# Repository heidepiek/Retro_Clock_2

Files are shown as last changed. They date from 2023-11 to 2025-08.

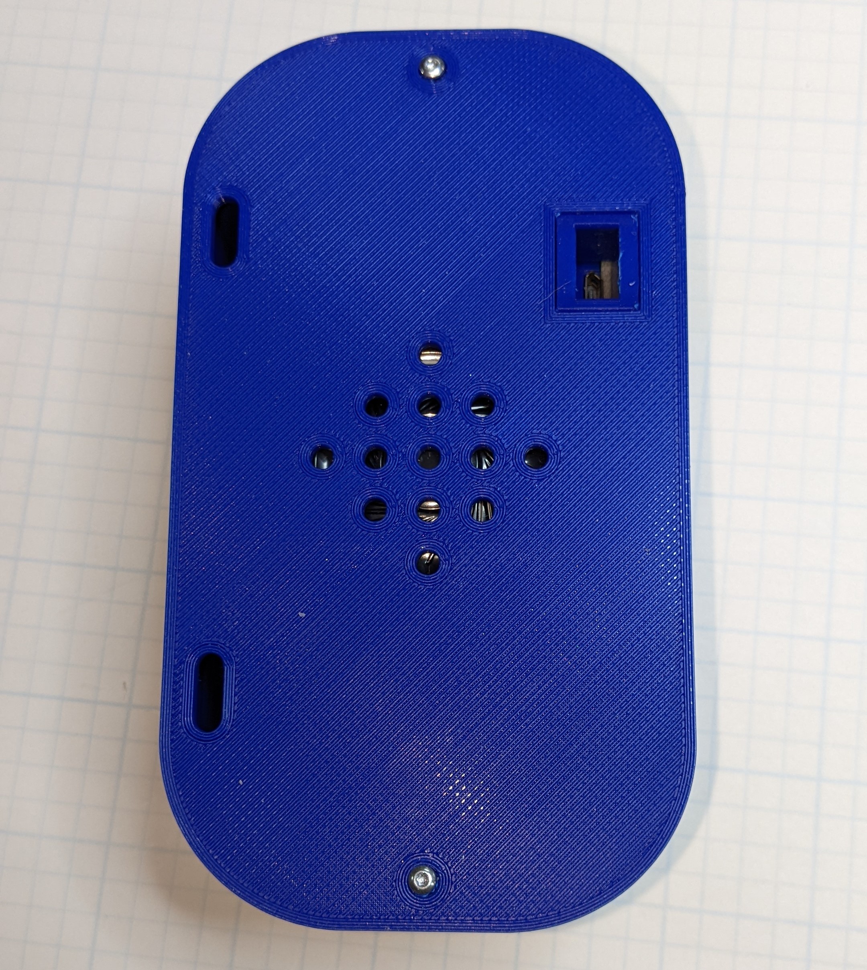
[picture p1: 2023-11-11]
Images/Rear_Cover_screws_Installed.jpg

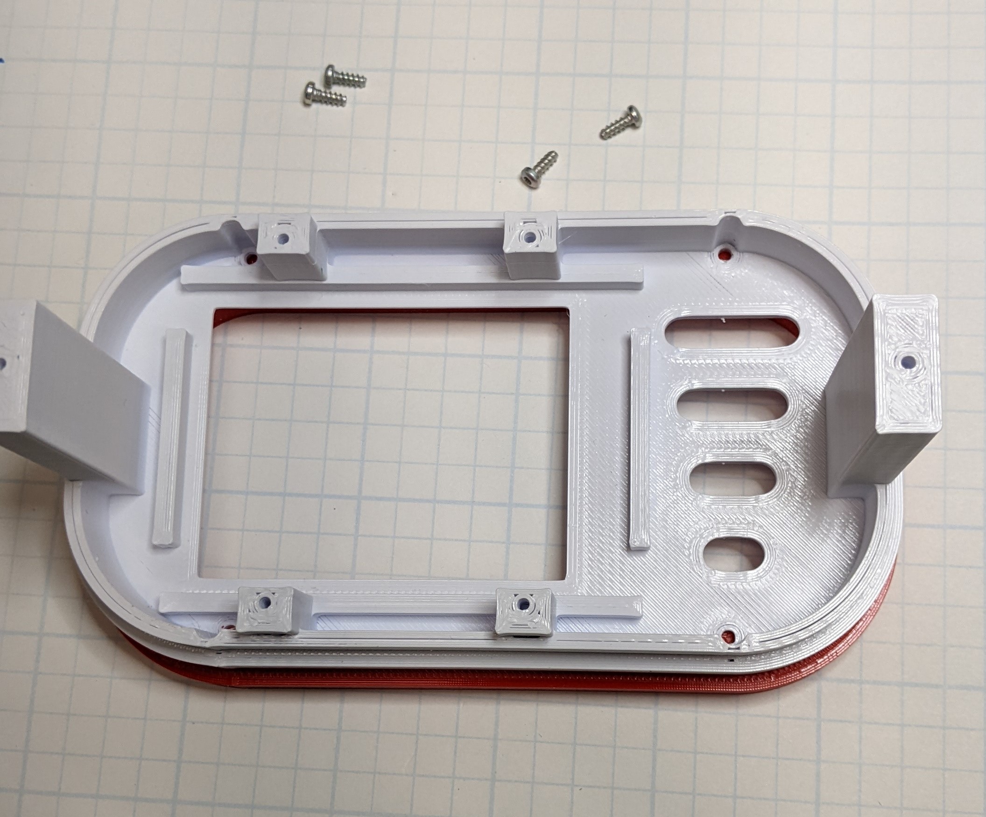
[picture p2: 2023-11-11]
Images/Bezel&TrimParts.jpg

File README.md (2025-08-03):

Pacman Clock

# Retro Clock 2

This is a personal customized version of the original ESP32 Pacman Clock project.  
I've added some visual and functional enhancements to suit my own preferences.

### My additions:
- Blinking dots between hours and minutes
- Rectangle around the time
- Date and day display
- Text below the time: “ESP32 Pacman Clock”
- Pacman and ghost icons

The rest of this README reflects the original project, which deserves full credit for the excellent foundation.

# Retro_Clock_2
 Improved version of Retro_Clock
 1. Redesigned all of clock case parts with freeCAD. results in cleaner parts.
 2. All STL files are from freeCAD redesign.
 3. Minor firmware changes. Added menu items.
 4. PCB redesign to use better audio amplifier.
 
# Retro_Clock
This is a highly modified version of TechKiwiGadgets clock found on 

1. Instructables     https://www.instructables.com/ESP32-Pacman-Clock/
2. Makerbot Thingiverse (ESP32 Pacman Clock)    https://www.thingiverse.com/thing:5136672

Modifications:
1. Changed TFT display to an SPI version which has a much improved Touch interface.
2. Added SPIFFS to support files for data and images. This freed up memory and added flexability.
3. Added support for optional RTC (real time clock IC). Improves time keeping accuracy.
4. Added support for LDR (light dependent resistor) so that display is dimmed at night.
5. Added audio amplifier (LM386) and volume control via touch screen.
6. Redesigned user interface (Touch menu) to support added features.
7. Made many changes to firmware to improve speed and readability. 
8. Designed PCB to support above mentioned changes.
9. Redesigned 3D printed parts to support hardware changes.

TFT_eSPI library:
1. The TFT_eSPI library requires it be changed to support each particular build (unusal but that's way way it works).
2. The file User_Setup_Select.h specifies which setup file in the User_Setups directory is to be used.
3. Added to the User_Setups directory is the file Setup_Pacman_Clock.h which contains the specifies the configuration and features (Touch) used by this project.
4. Move the file "Setup_Pacman_Clock.h" into directory   ...Arduino/libraries/TFT_eSPI/User_Setups
5. Move the file "User_Setup_Select.h" into the directory    ...Arduino/libraries/TFT_eSPI   (replaces the existing User_Setup_Select.h file). 

Tools:
1. Arduino IDE 1.8.19, Board: DOIT ESP32 DEVKIT V1
2. Initialize SPIFFS using Arduino IDE  "Tools/ESP32 Sketch Data Upload" (which will initializee SPIFFS and upload all the files from the Data directory).
3. Creality Slicer, PLA, 0.2mm, no supports.

Additional Notes:
1. 	Arduino Sketch (IDE) Version 1.8.19
2.	Board Manager -> esp32 by Espressif Systems Version 1.0.6
3.	Libraries used:

		TFT_eSPI at version 2.5.0
		RTClib at version 2.1.1
		Wire at version 1.0.1
		SPIFFS at version 1.0
		FS at version 1.0
		XT_DAC_Audio
		Time at version 1.6.1
		Adafruit_BusIO at version 1.14.1
4.	TFT_eSPI setup file contains (see TFT_eSPI folder in Arduino/libraries):

		#define USER_SETUP_ID 900
		#define ILI9341_DRIVER
		#define TFT_MISO	19
		#define TFT_MOSI	23
		#define TFT_SCLK	18
		#define TFT_CS		15
		#define TFT_DC		4
		#define TFT_RST		2

		#define TOUCH_CS	5		// Required to enable Touch, getTouch()

		#define LOAD_GLCD
		#define LOAD_FONT2
		#define LOAD_FONT4
		#define LOAD FONT6
		#define LOAD_FONT7
		#define LOAD_FONT8
		#define LOAD_GFXFF
		#define SMOOTH_FONT

		#define SPI_FREQUENCY 27000000					// 27 MHz
		#define SPI_READ_FREQUENCY 20000000				// 20 MHz
		#define SPI_TOUCH_FREQUENCY 2500000				// 2.5 MHz

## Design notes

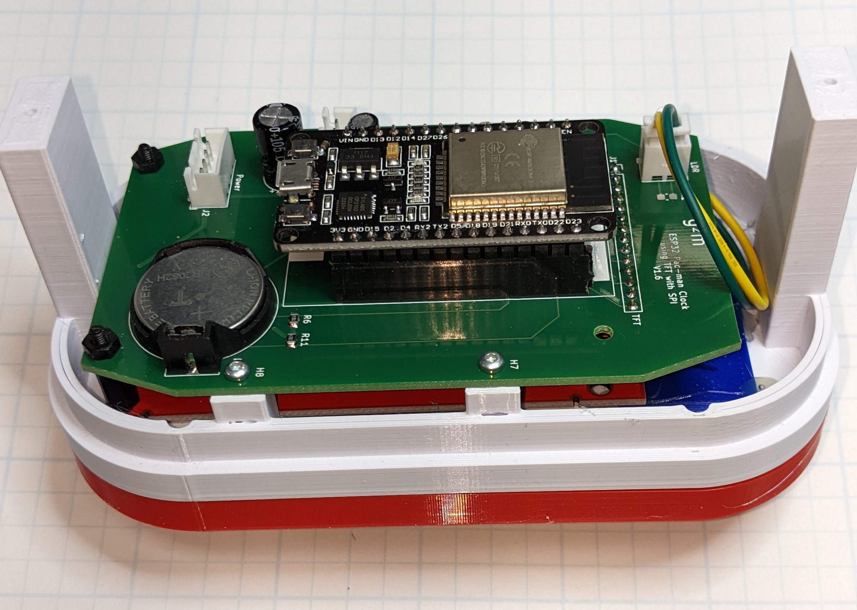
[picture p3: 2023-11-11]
Images/Bezel_with_PCB.jpg

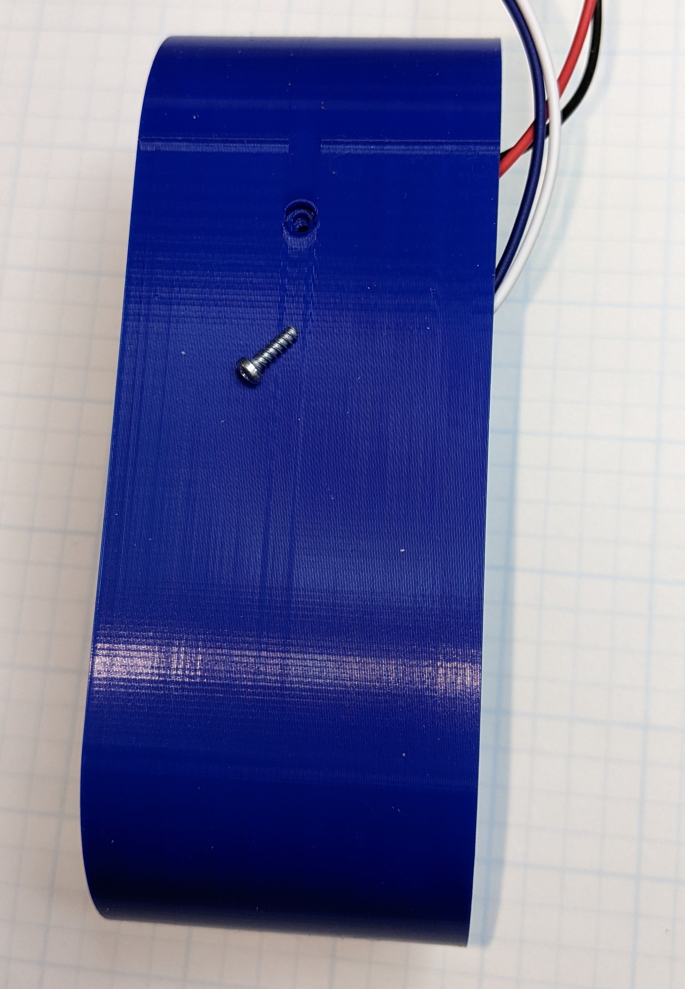
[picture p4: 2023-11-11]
Images/USB_Securing_Screw.jpg

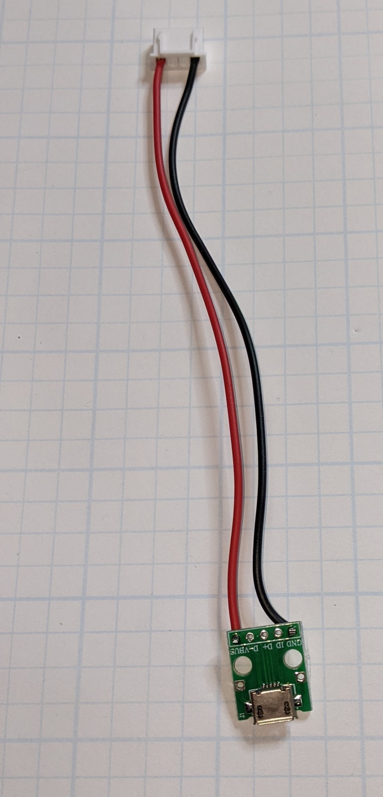
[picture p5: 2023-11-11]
Images/USB.jpg

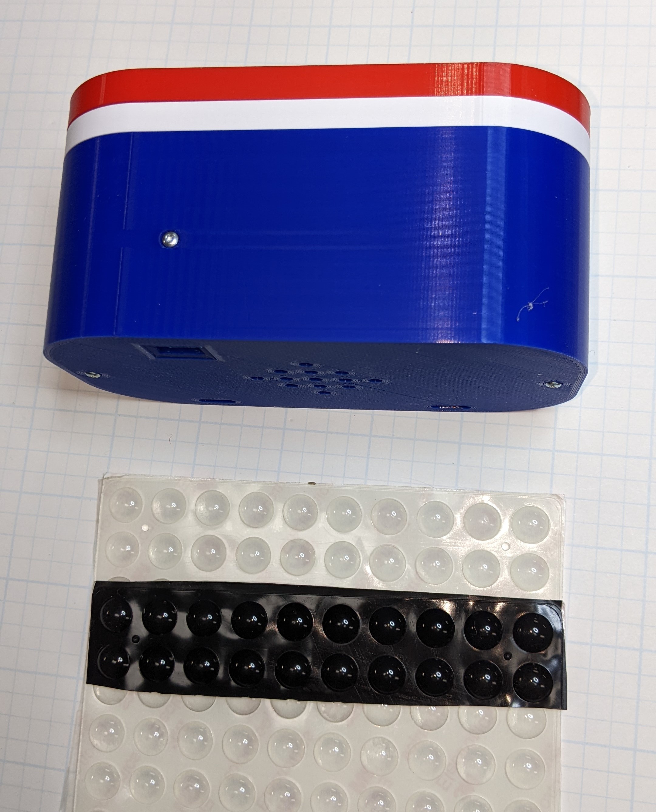
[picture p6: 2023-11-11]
Images/Clock_Case_&_Rubber_Feet.jpg

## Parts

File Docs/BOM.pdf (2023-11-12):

Component Count: | 33
Ref | Value | Footprint | Amazon (search) | Notes
BT1 | Holder | KiCab_g2m_Lib:2032BatteryHolderHoriz | | See note on U3,. Used battery holder from
| | | | DS3231 board.
C1 | 390nF | Capacitor_SMD:C_0805_2012Metric_Pad | 0805 SMD Capacitor Assorted Kit 1pF-1uF Chip
| | | Ceramic Capacitor
C2 | 1uF | Capacitor_SMD:C_1206_3216Metric_Pad | 1206 SMD Capacitor Assorted Kit 10P-22UF Chip
| | | Ceramic Capacitor
C3 | 470uF | Capacitor_THT:CP_Radial_D8.0mm_P3.50mm | lectrolytic Capacitor 470uF 16V with Aluminum Radial
| | | Leads 470UF-16V-8X12
C4 | 1uF | Capacitor_SMD:C_1206_3216Metric_Pad | 1206 SMD Capacitor Assorted Kit 10P-22UF Chip
| | | Ceramic Capacitor
C5 | 10uF | Capacitor_THT:CP_Radial_D4.0mm_P1.50mm | Electrolytic Capacitor 10uF 25V with Aluminum Radial
| | | Leads 10UF-25V-4X7
C6 | 1uF | Capacitor_SMD:C_0805_2012Metric_Pad | 0805 SMD Capacitor Assorted Kit 1pF-1uF Chip
| | | Ceramic Capacitor
C8 | 100nF | Capacitor_SMD:C_0805_2012Metric_Pad | 0805 SMD Capacitor Assorted Kit 1pF-1uF Chip
| | | Ceramic Capacitor
D1 | 1N4148W | Diode_SMD:D_SOD-123 | | See U3. Used diode from DS3231 board.
H1 | MountingHole | MountingHole:MountingHole_2.7mm_M2.5_DIN965
H2 | MountingHole | MountingHole:MountingHole_2.7mm_M2.5_DIN965
H3 | MountingHole | MountingHole:MountingHole_2.7mm_M2.5_DIN965
H4 | MountingHole | MountingHole:MountingHole_2.7mm_M2.5_DIN965
H5 | MountingHole | MountingHole:MountingHole_2.7mm_M2.5_DIN965
H6 | MountingHole | MountingHole:MountingHole_2.7mm_M2.5_DIN965
H7 | MountingHole | MountingHole:MountingHole_2.7mm_M2.5_DIN965
H8 | MountingHole | MountingHole:MountingHole_2.7mm_M2.5_DIN965
J1 | TFT Connector | Connector_PinSocket_2.54mm:PinSocket_1x14_P2.54mm_Vertical | 40 Pin 2.54mm Single Row Straight Female PCB
| | | Header Connector Strip | Cut strip to required length - 14 pins.
J2 | Power | Connector_JST:JST_XH_B4B-XH-A_1x04_P2.50mm_Vertical | JST-XH 2.54mm Connector Kit, 2.54mm Male and
| | | Female 2/3/4/5/6 Pin Header Housing Connector
J3 | Speaker | Connector_JST:JST_XH_B2B-XH-A_1x02_P2.50mm_Vertical | JST-XH 2.54mm Connector Kit, 2.54mm Male and
| | | Female 2/3/4/5/6 Pin Header Housing Connector
J4 | LDR | Connector_JST:JST_XH_B2B-XH-A_1x02_P2.50mm_Vertical | JST-XH 2.54mm Connector Kit, 2.54mm Male and
| | | Female 2/3/4/5/6 Pin Header Housing Connector
R1 | 20k | Resistor_SMD:R_0805_2012Metric_Pad | 0805 SMD Resistor Kit 0-10M Ω ohm
R2 | 200 | Resistor_SMD:R_0805_2012Metric_Pad | 0805 SMD Resistor Kit 0-10M Ω ohm | Only installed if LDR option is not used.
R6 | 4.7k | Resistor_SMD:R_0805_2012Metric_Pad | 0805 SMD Resistor Kit 0-10M Ω ohm
R7 | 10k | Resistor_SMD:R_0805_2012Metric_Pad | 0805 SMD Resistor Kit 0-10M Ω ohm
R8 | 20k | Resistor_SMD:R_0805_2012Metric_Pad | 0805 SMD Resistor Kit 0-10M Ω ohm
R10 | 20k | Resistor_SMD:R_0805_2012Metric_Pad | 0805 SMD Resistor Kit 0-10M Ω ohm
R11 | 4.7k | Resistor_SMD:R_0805_2012Metric_Pad | 0805 SMD Resistor Kit 0-10M Ω ohm
R12 | 200 | Resistor_SMD:R_0805_2012Metric_Pad | 0805 SMD Resistor Kit 0-10M Ω ohm
SW1 | Recal Touch | Tactile-switch:FSM2JRT_gm | 6x6x7mm 2 Pin Panel PCB Momentary Tactile Tact
| | | Push Button Switch Through Hole Installation
U1 | LM4890M_NOPB | Package_SO:SOIC-8_3.9x4.9mm_P1.27mm | | Mouser: 926-LM4890M/NOPB
U2 | ESP-WROOM-32S | If Socketed (recommended) - uses two of the following connectors
| | Connector_PinSocket_2.54mm:PinSocket_1x15_P2.54mm_Vertical | 40 Pin 2.54mm Single Row Straight Female PCB
| | | Header Connector Strip | Cut strip to required length - 15 pins.
| | | | Quantity 2.

Retro Clock 2

U3 | DS3231M | Package_SO:SOIC-16W_7.5x10.3mm_P1.27mm

DS3231 AT24C32 Clock Module Real Time Clock Module IIC RTC Module

Ordering from Amazon is much less expensive. Although you will need to remove the DS3231 and battery holder from the board.

Battery | LIR2032 | Rechargeable 2032 Battery, 3.7V

LIR2032 Rechargeable Batteries 3.7V with High Capacity 70mA
TFT | 2.8 inch TFT with Touch, SPI interface. | ILI9341 2.8" SPI TFT LCD Display Touch Panel 240X320
ESP32S | ESP32S | ESP32S Module - 30 pins (2 rows of 15 pins)

ESP-WROOM-32 ESP32 ESP-32S Development Board 2.4GHz Dual-Mode WiFi + Bluetooth Dual Cores Microcontroller Processor Integrated with Antenna RF AMP Filter AP STA Compatible

Screws - 6mm
Qty 9

Torx Plus Rounded Head Thread-Forming Screws for Plastic, Zinc-Plated Steel, M2.26 Size, 6 mm Long

McMaster-Carr mcmaster.com

### 4 to mount Bezel Trim to Bezel 4 to mount PCB to Bezel 1 to mount USB Bracket to Rear Case

Screws - 8mm
Qty 2

Torx Plus Rounded Head Thread-Forming Screws for Plastic, Zinc-Plated Steel, M2.26 Size, 8 mm Long

McMaster-Carr mcmaster.com | 2 to mount Rear Case to Bezel
Screws - 10mm
Qty 2

Torx Plus Rounded Head Thread-Forming Screws for Plastic, Zinc-Plated Steel, M2.26 Size, 10 mm Long

McMaster-Carr mcmaster.com | 2 to mount USB Lock and USB Connector board to USB bracket

Glue

Either hot-glue or super-glue Decal to Bezel. Hot glue LDR to Decal.

Hardware

Plug-in Devices

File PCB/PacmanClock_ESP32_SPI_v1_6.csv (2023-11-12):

Source: | C:\Users\gmaur\Documents\GitHub\Retro_Clock_2\PCB\PacmanClock_ESP32_SPI_v1_6.sch
Date: | 11/12/2023 1:09:07 PM
Tool: | Eeschema (5.1.10)-1
Component Count: | 33
Ref | Value | Footprint | Datasheet | Manufacturer | Vendor
BT1 | LIR2032 | KiCab_g2m_Lib:2032BatteryHolderHoriz | ~
C1 | 390nF | Capacitor_SMD:C_0805_2012Metric_Pad1.18x1.45mm_HandSolder | ~
C2 | 1uF | Capacitor_SMD:C_1206_3216Metric_Pad1.33x1.80mm_HandSolder | ~
C3 | 470uF | Capacitor_THT:CP_Radial_D8.0mm_P3.50mm | ~
C4 | 1uF | Capacitor_SMD:C_1206_3216Metric_Pad1.33x1.80mm_HandSolder | ~
C5 | 10uF | Capacitor_THT:CP_Radial_D4.0mm_P1.50mm | ~
C6 | 1uF | Capacitor_SMD:C_0805_2012Metric_Pad1.18x1.45mm_HandSolder | ~
C8 | 100nF | Capacitor_SMD:C_0805_2012Metric_Pad1.18x1.45mm_HandSolder | ~
D1 | 1N4148W | Diode_SMD:D_SOD-123 | https://www.vishay.com/docs/85748/1n4148w.pdf
H1 | MountingHole | MountingHole:MountingHole_2.7mm_M2.5_DIN965 | ~
H2 | MountingHole | MountingHole:MountingHole_2.7mm_M2.5_DIN965 | ~
H3 | MountingHole | MountingHole:MountingHole_2.7mm_M2.5_DIN965 | ~
H4 | MountingHole | MountingHole:MountingHole_2.7mm_M2.5_DIN965 | ~
H5 | MountingHole | MountingHole:MountingHole_2.7mm_M2.5_DIN965 | ~
H6 | MountingHole | MountingHole:MountingHole_2.7mm_M2.5_DIN965 | ~
H7 | MountingHole | MountingHole:MountingHole_2.7mm_M2.5_DIN965 | ~
H8 | MountingHole | MountingHole:MountingHole_2.7mm_M2.5_DIN965 | ~
J1 | TFT | Connector_PinSocket_2.54mm:PinSocket_1x14_P2.54mm_Vertical | ~
J2 | Power | Connector_JST:JST_XH_B4B-XH-A_1x04_P2.50mm_Vertical | ~
J3 | Speaker | Connector_JST:JST_XH_B2B-XH-A_1x02_P2.50mm_Vertical | ~
J4 | LDR | Connector_JST:JST_XH_B2B-XH-A_1x02_P2.50mm_Vertical | ~
R1 | 20k | Resistor_SMD:R_0805_2012Metric_Pad1.20x1.40mm_HandSolder | ~
R2 | 200 | Resistor_SMD:R_0805_2012Metric_Pad1.20x1.40mm_HandSolder | ~
R6 | 4.7k | Resistor_SMD:R_0805_2012Metric_Pad1.20x1.40mm_HandSolder | ~
R7 | 10k | Resistor_SMD:R_0805_2012Metric_Pad1.20x1.40mm_HandSolder | ~
R8 | 20k | Resistor_SMD:R_0805_2012Metric_Pad1.20x1.40mm_HandSolder | ~
R10 | 20k | Resistor_SMD:R_0805_2012Metric_Pad1.20x1.40mm_HandSolder | ~
R11 | 4.7k | Resistor_SMD:R_0805_2012Metric_Pad1.20x1.40mm_HandSolder | ~
R12 | 200 | Resistor_SMD:R_0805_2012Metric_Pad1.20x1.40mm_HandSolder | ~
SW1 | Recal Touch | Tactile-switch:FSM2JRT_gm | ~
U1 | LM4890M_NOPB | Package_SO:SOIC-8_3.9x4.9mm_P1.27mm | http://www.ti.com/lit/ds/symlink/lm4890.pdf
U2 | ESP-WROOM-32S | ESP32-Footprints:ESP-WROOM-32S
U3 | DS3231M | Package_SO:SOIC-16W_7.5x10.3mm_P1.27mm | http://datasheets.maximintegrated.com/en/ds/DS3231.pdf

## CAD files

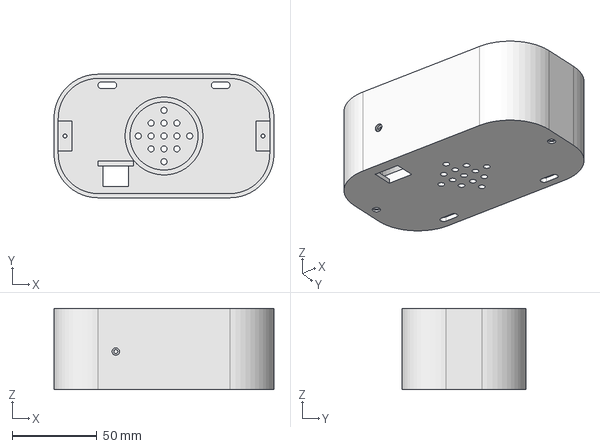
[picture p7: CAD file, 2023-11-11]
Case/freeCAD_Files/ClockAssembly.FCStd
130.0 x 73.0 x 48.0 mm

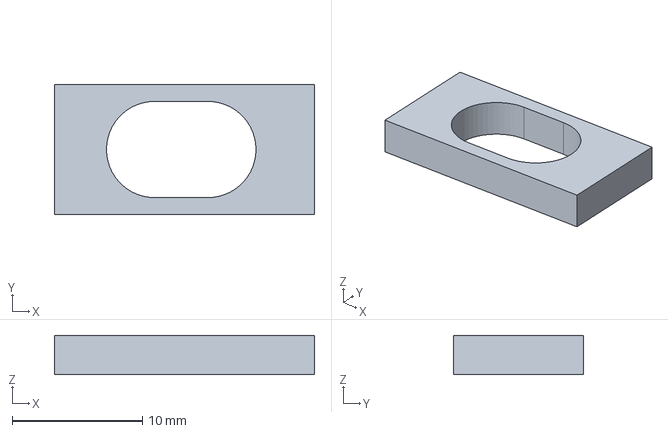
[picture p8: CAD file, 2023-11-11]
Case/freeCAD_Files/NU_USB_C_Test.FCStd
20.0 x 10.0 x 3.00 mm

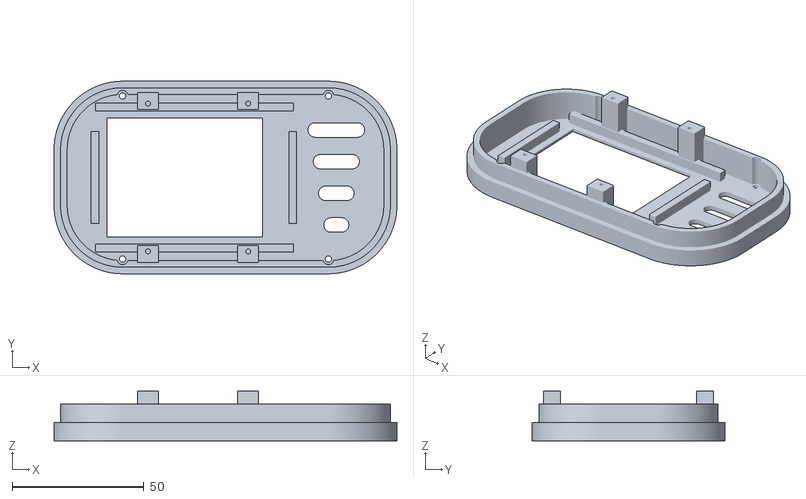
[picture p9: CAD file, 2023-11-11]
Case/STL_Files/NU_CLOCK_BEZEL-Body.stl
130.0 x 73.0 x 18.9

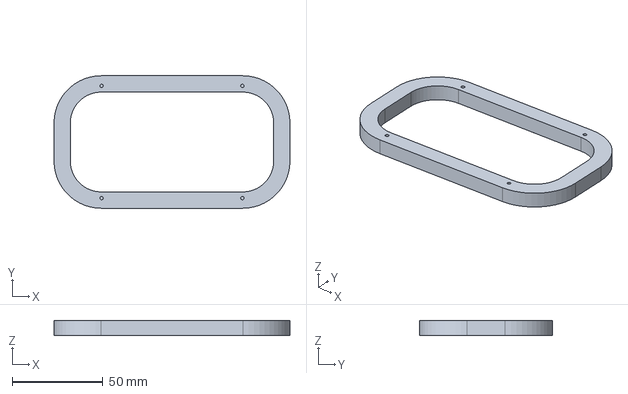
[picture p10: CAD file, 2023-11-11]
Case/freeCAD_Files/NU_BEZEL_TRIMStd.FCStd
130.0 x 73.0 x 8.00 mm

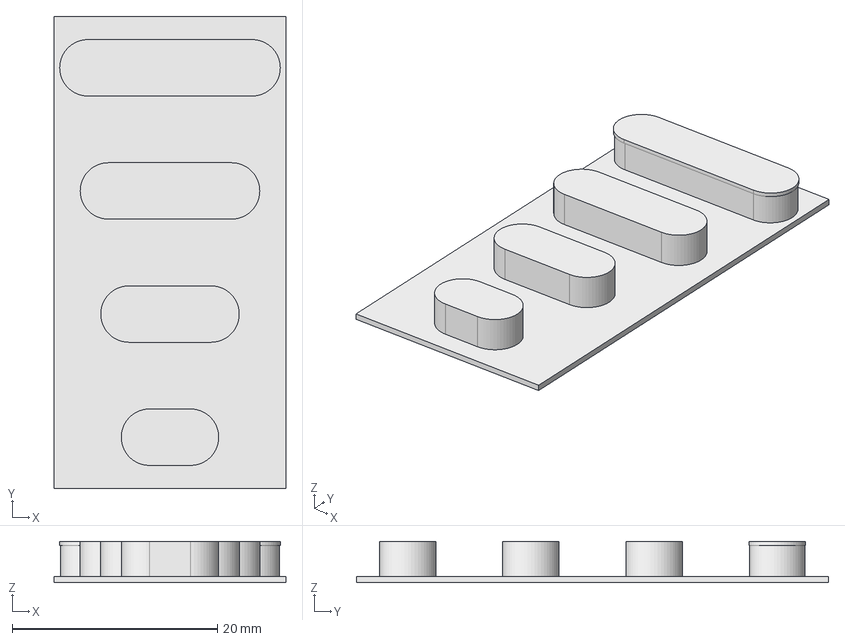
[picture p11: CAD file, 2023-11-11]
Case/freeCAD_Files/NU_DECAL.FCStd
22.6 x 46.0 x 4.00 mm

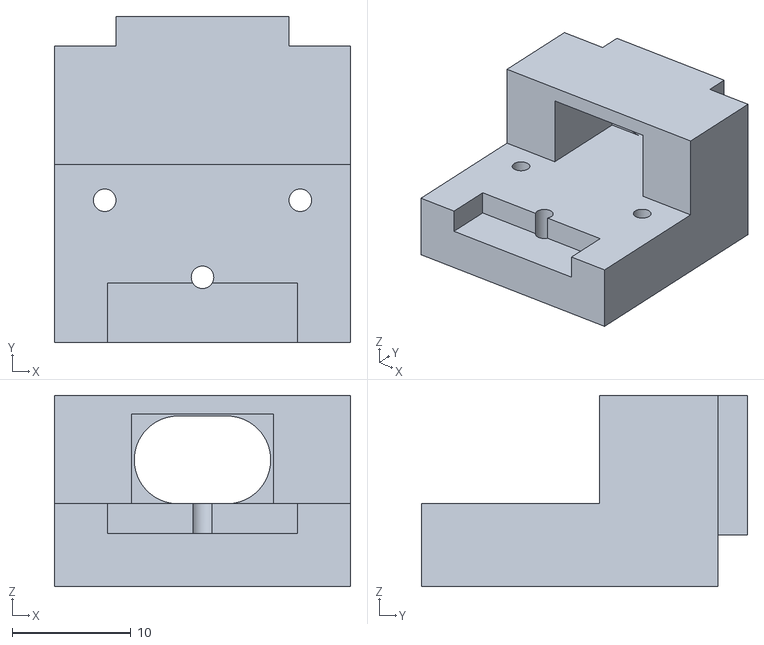
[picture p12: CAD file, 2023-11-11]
Case/STL_Files/NU_USB_C_Bracket2.stl
25.0 x 27.5 x 16.1

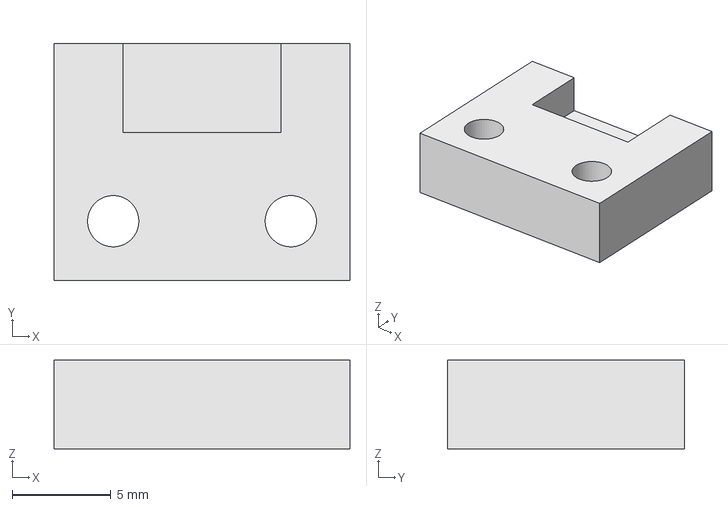
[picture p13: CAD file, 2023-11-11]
Case/freeCAD_Files/NU_USB_Micro_Lock.FCStd
15.0 x 12.0 x 4.50 mm

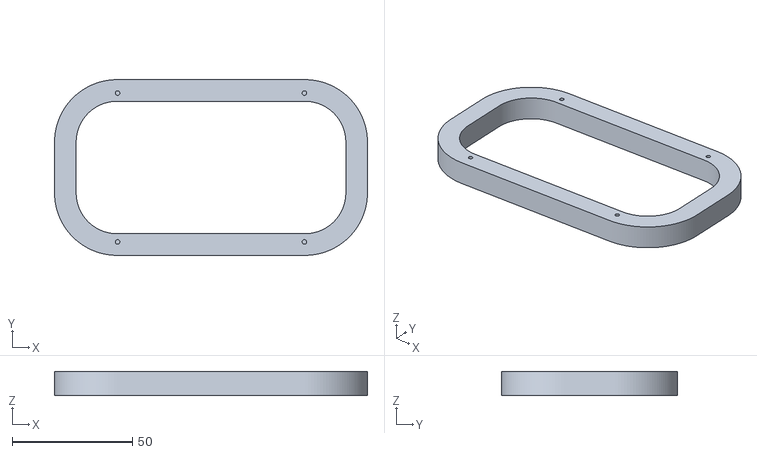
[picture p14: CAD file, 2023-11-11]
Case/STL_Files/NU_BEZEL-Part.stl
130.0 x 73.0 x 10.0

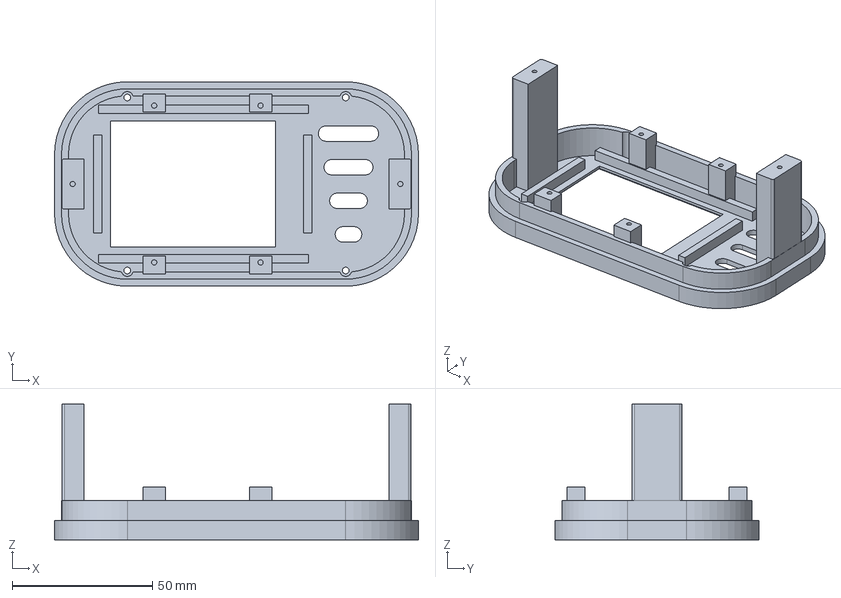
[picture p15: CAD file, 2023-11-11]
Case/freeCAD_Files/NU_CLOCK_BEZEL.FCStd
130.0 x 73.0 x 48.5 mm

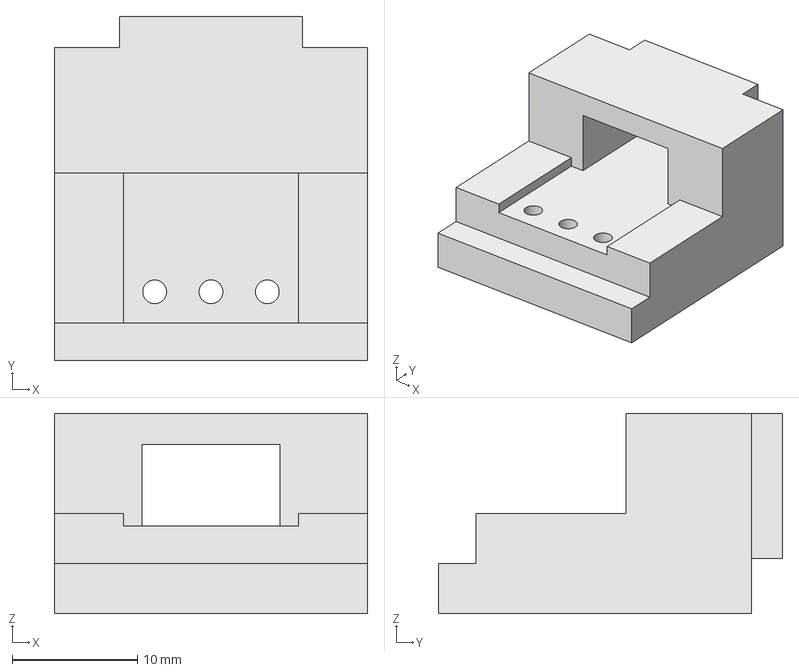
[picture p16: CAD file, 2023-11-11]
Case/freeCAD_Files/NU_USB_Micro_Bracket.FCStd
25.0 x 27.5 x 16.0 mm

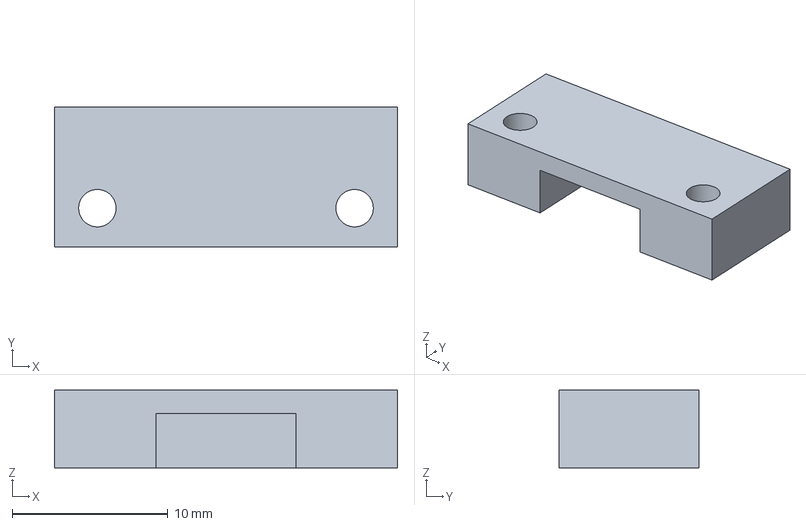
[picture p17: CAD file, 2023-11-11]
Case/freeCAD_Files/NU_USB_C_Lock.FCStd
22.0 x 9.00 x 5.00 mm

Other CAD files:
Case/freeCAD_Files/NU_CLOCK_CASE.FCStd
Case/STL_Files/NU_CLOCK_CASE-PartBody.stl
Case/STL_Files/NU_BEZEL_Trim.stl
Case/freeCAD_Files/NU_BEZEL.FCStd
Case/STL_Files/NU_BEZEL-PartBody1.stl
Case/freeCAD_Files/NU_USB_C_Bracket.FCStd
Case/freeCAD_Files/NU_DECAL2.FCStd
Case/STL_Files/NU_BEZEL.stl
Case/STL_Files/NU_CLOCK_CASE.stl
Case/STL_Files/NU_DECAL.stl
Case/STL_Files/NU_DECAL2.stl
Case/STL_Files/NU_USB_C_Bracket.stl
Case/STL_Files/NU_USB_C_Lock.stl
Case/STL_Files/NU_USB_C_Test.stl
Case/STL_Files/NU_USB_Micro_Bracket.stl
Case/STL_Files/NU_USB_Micro_Lock.stl

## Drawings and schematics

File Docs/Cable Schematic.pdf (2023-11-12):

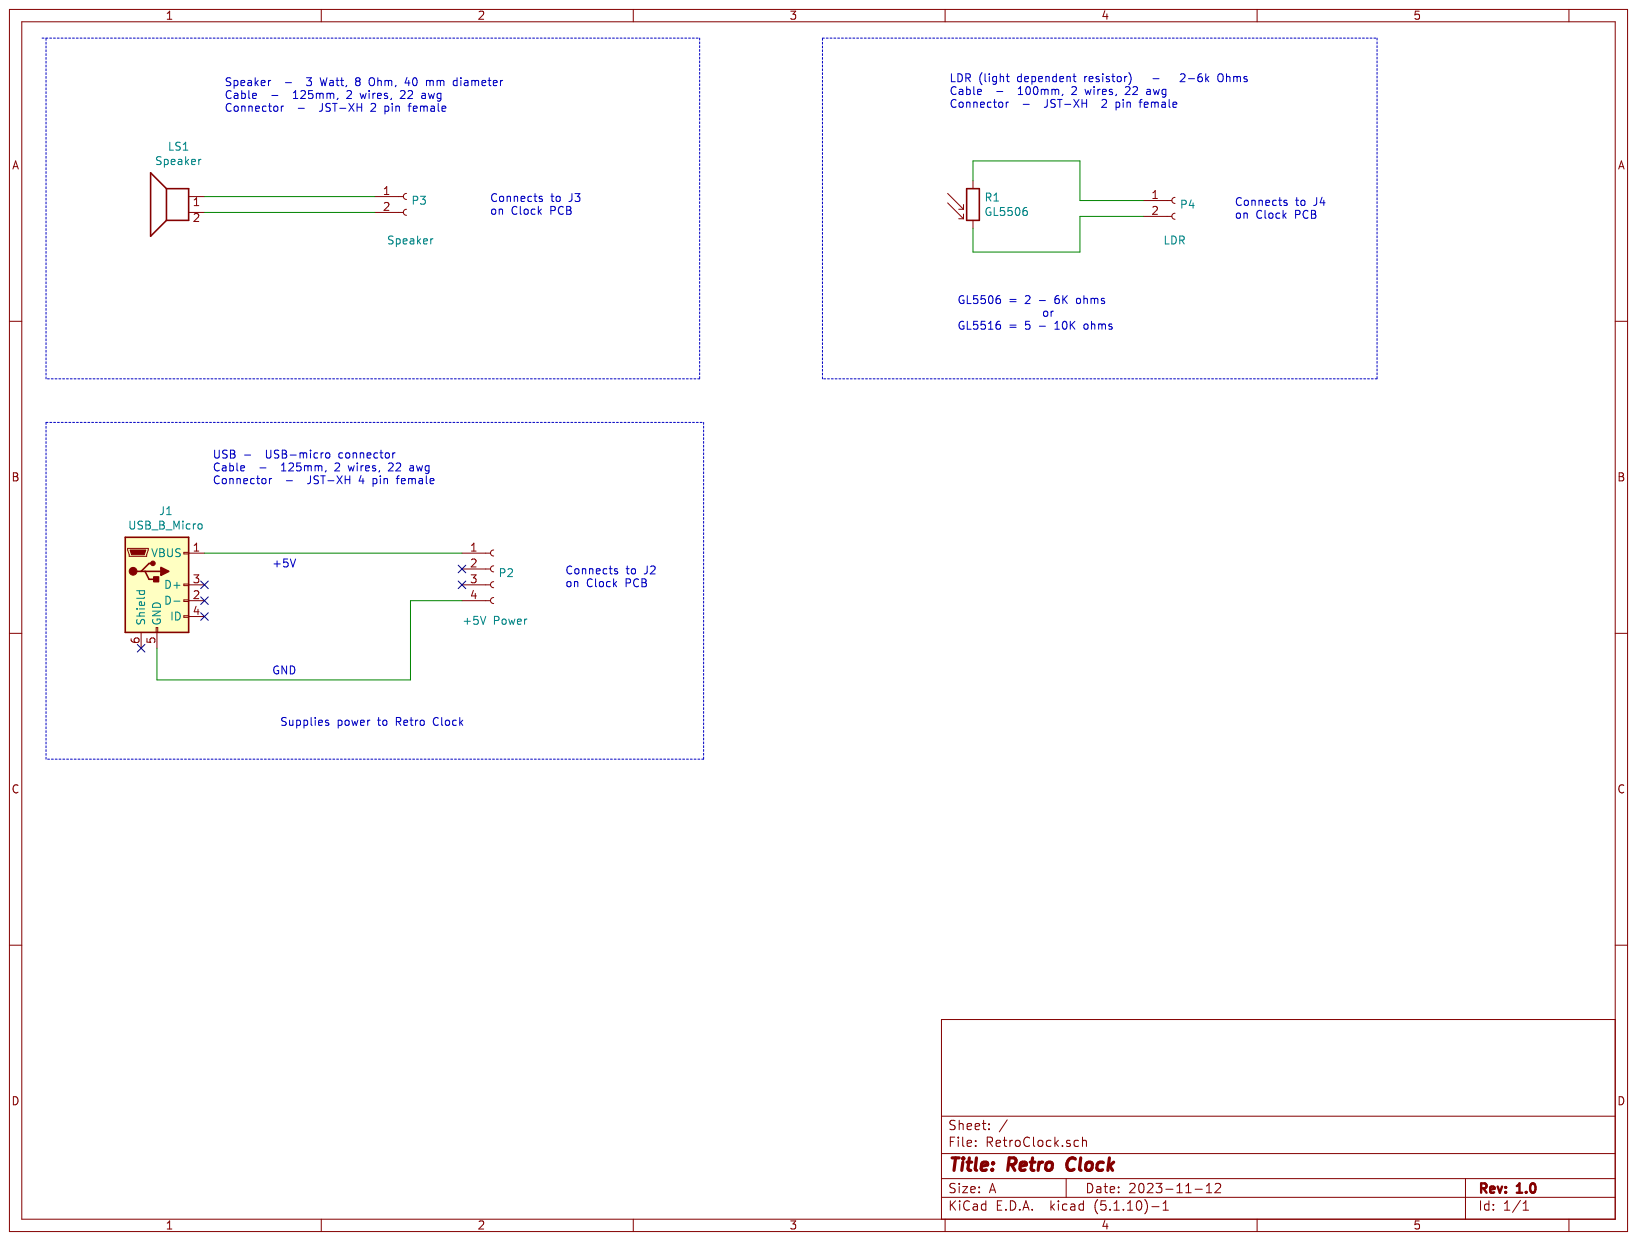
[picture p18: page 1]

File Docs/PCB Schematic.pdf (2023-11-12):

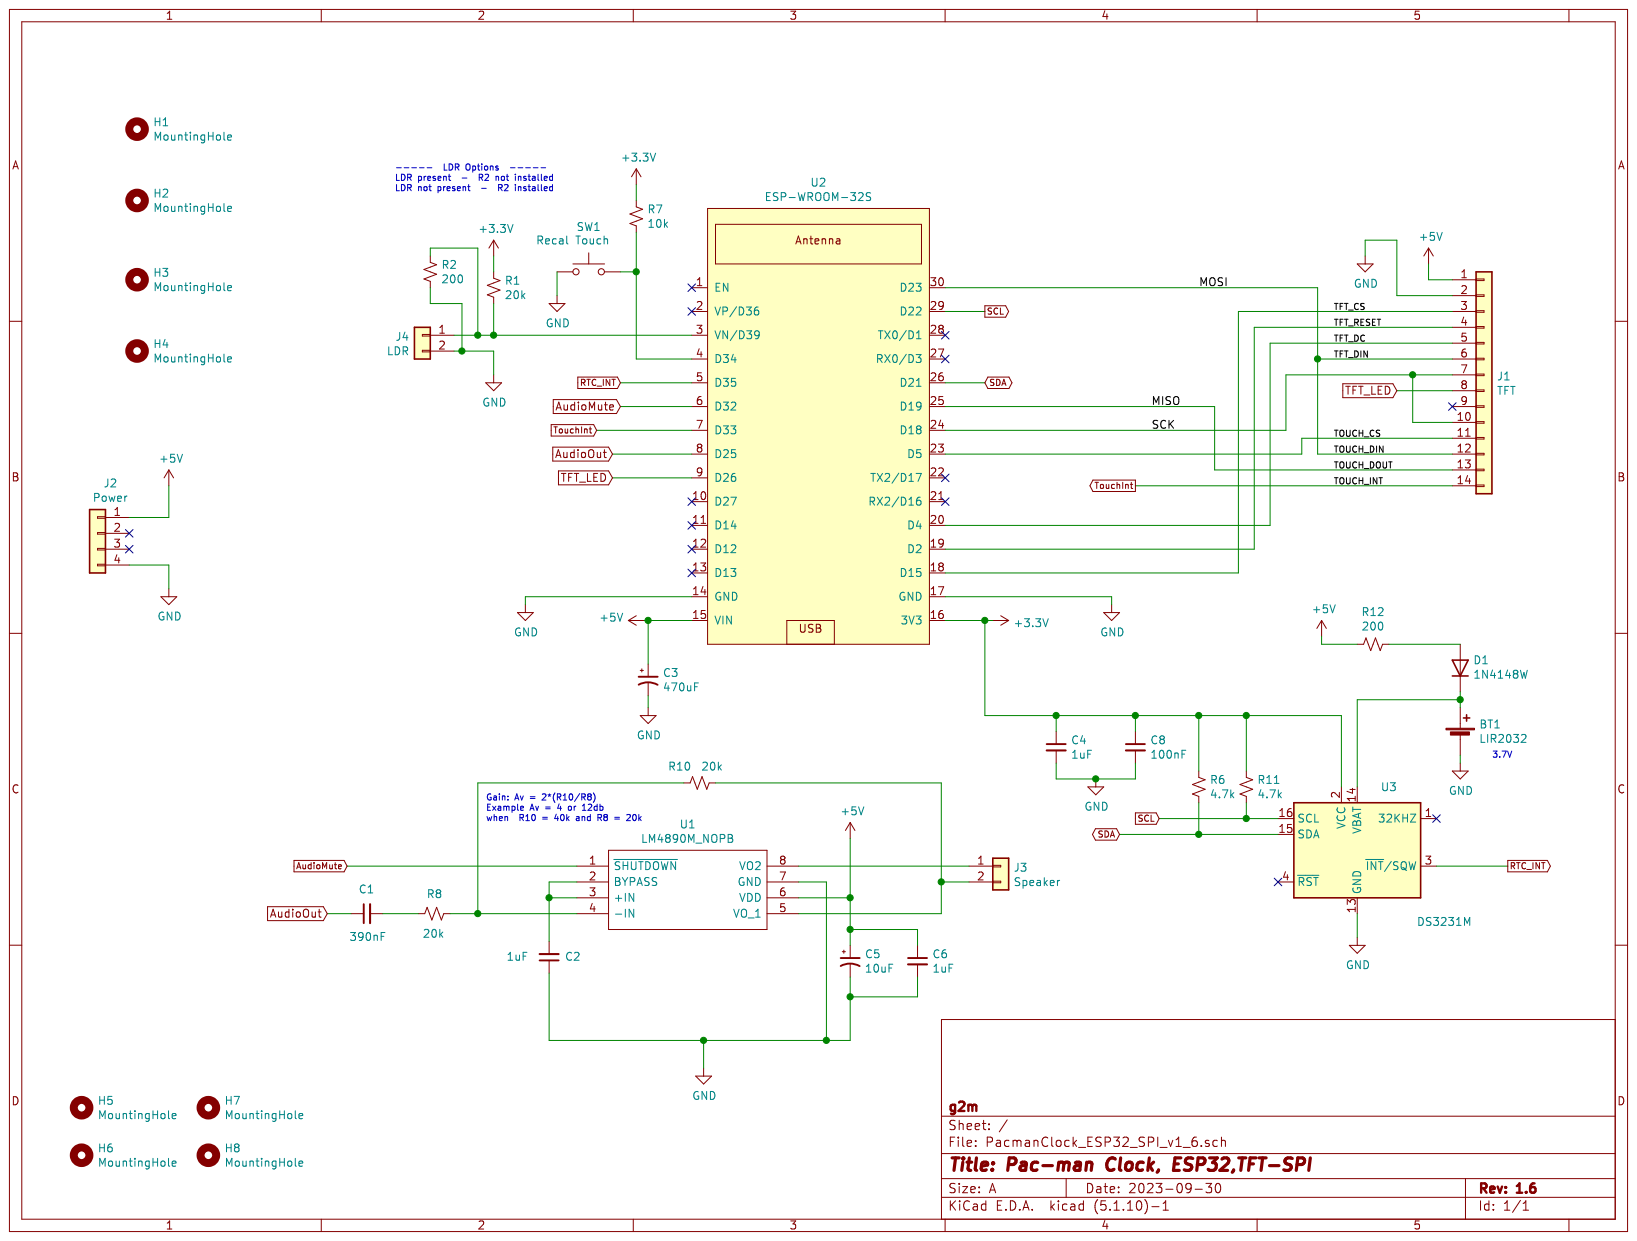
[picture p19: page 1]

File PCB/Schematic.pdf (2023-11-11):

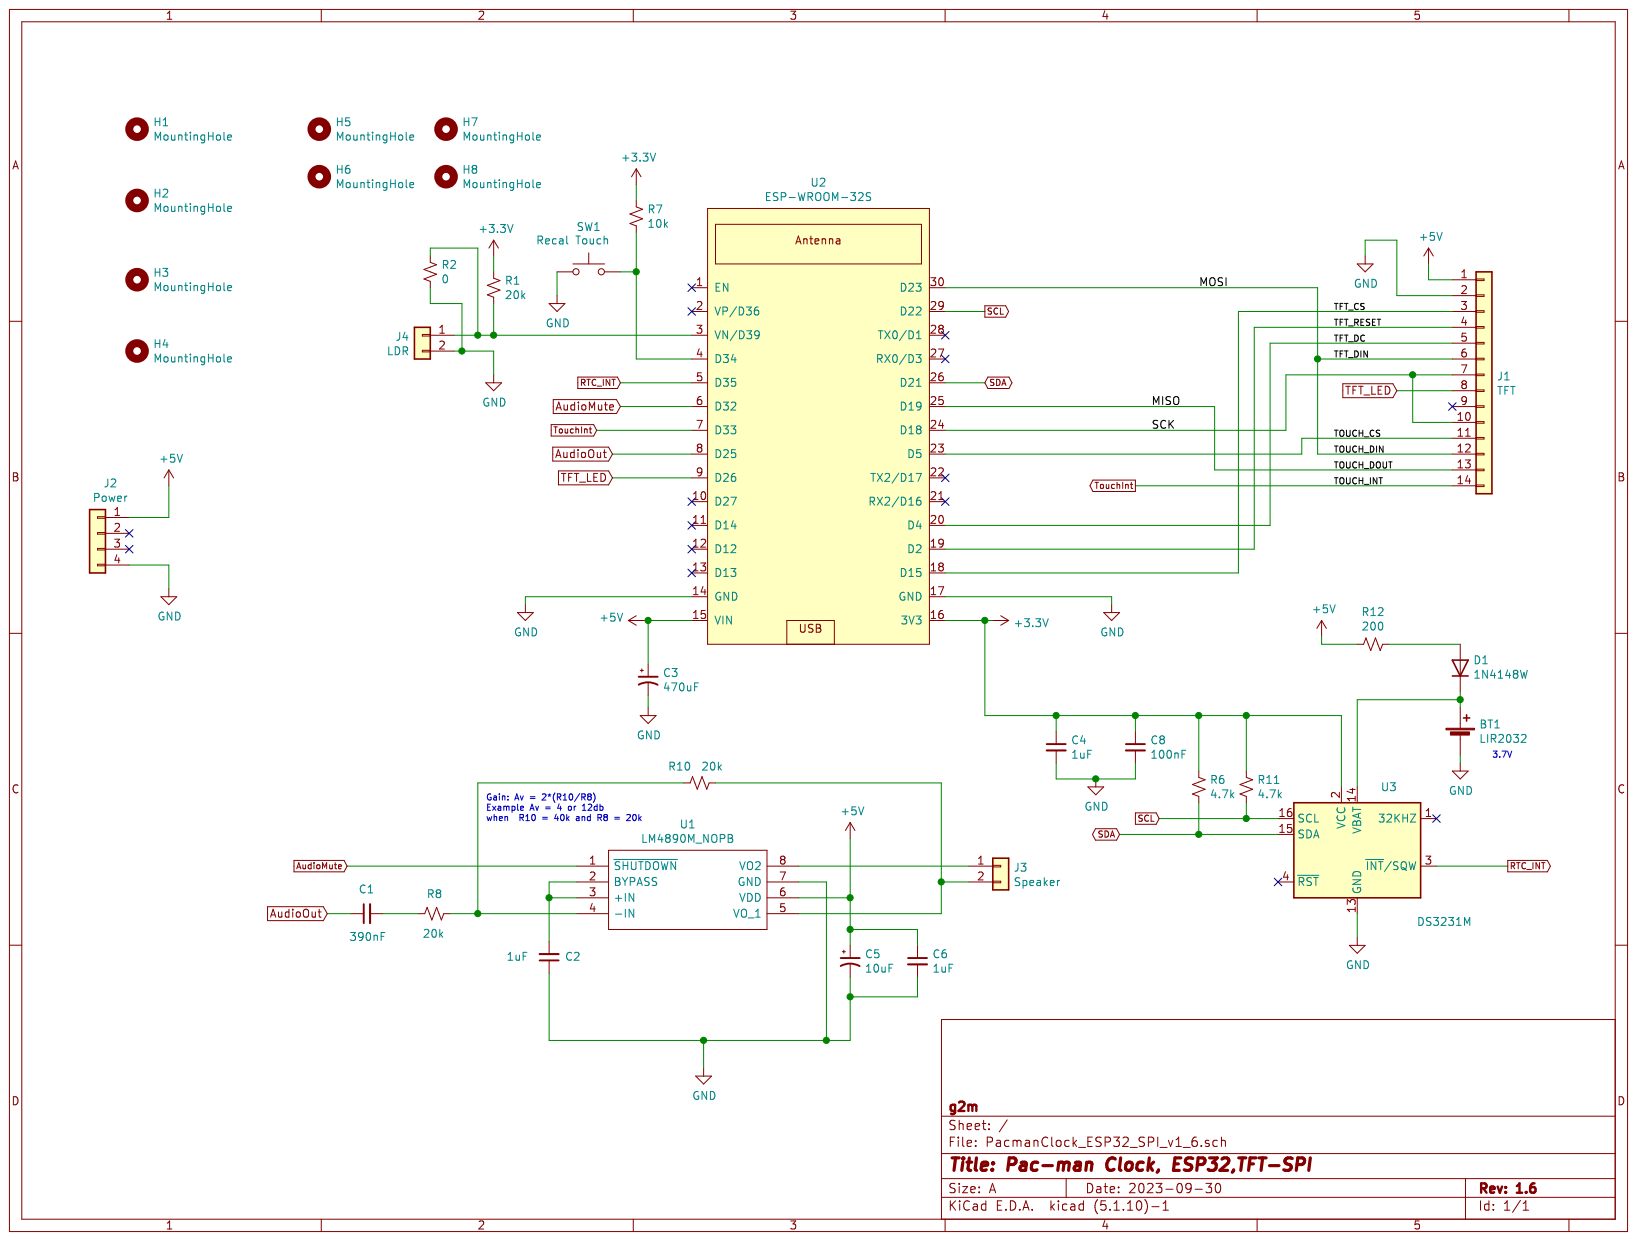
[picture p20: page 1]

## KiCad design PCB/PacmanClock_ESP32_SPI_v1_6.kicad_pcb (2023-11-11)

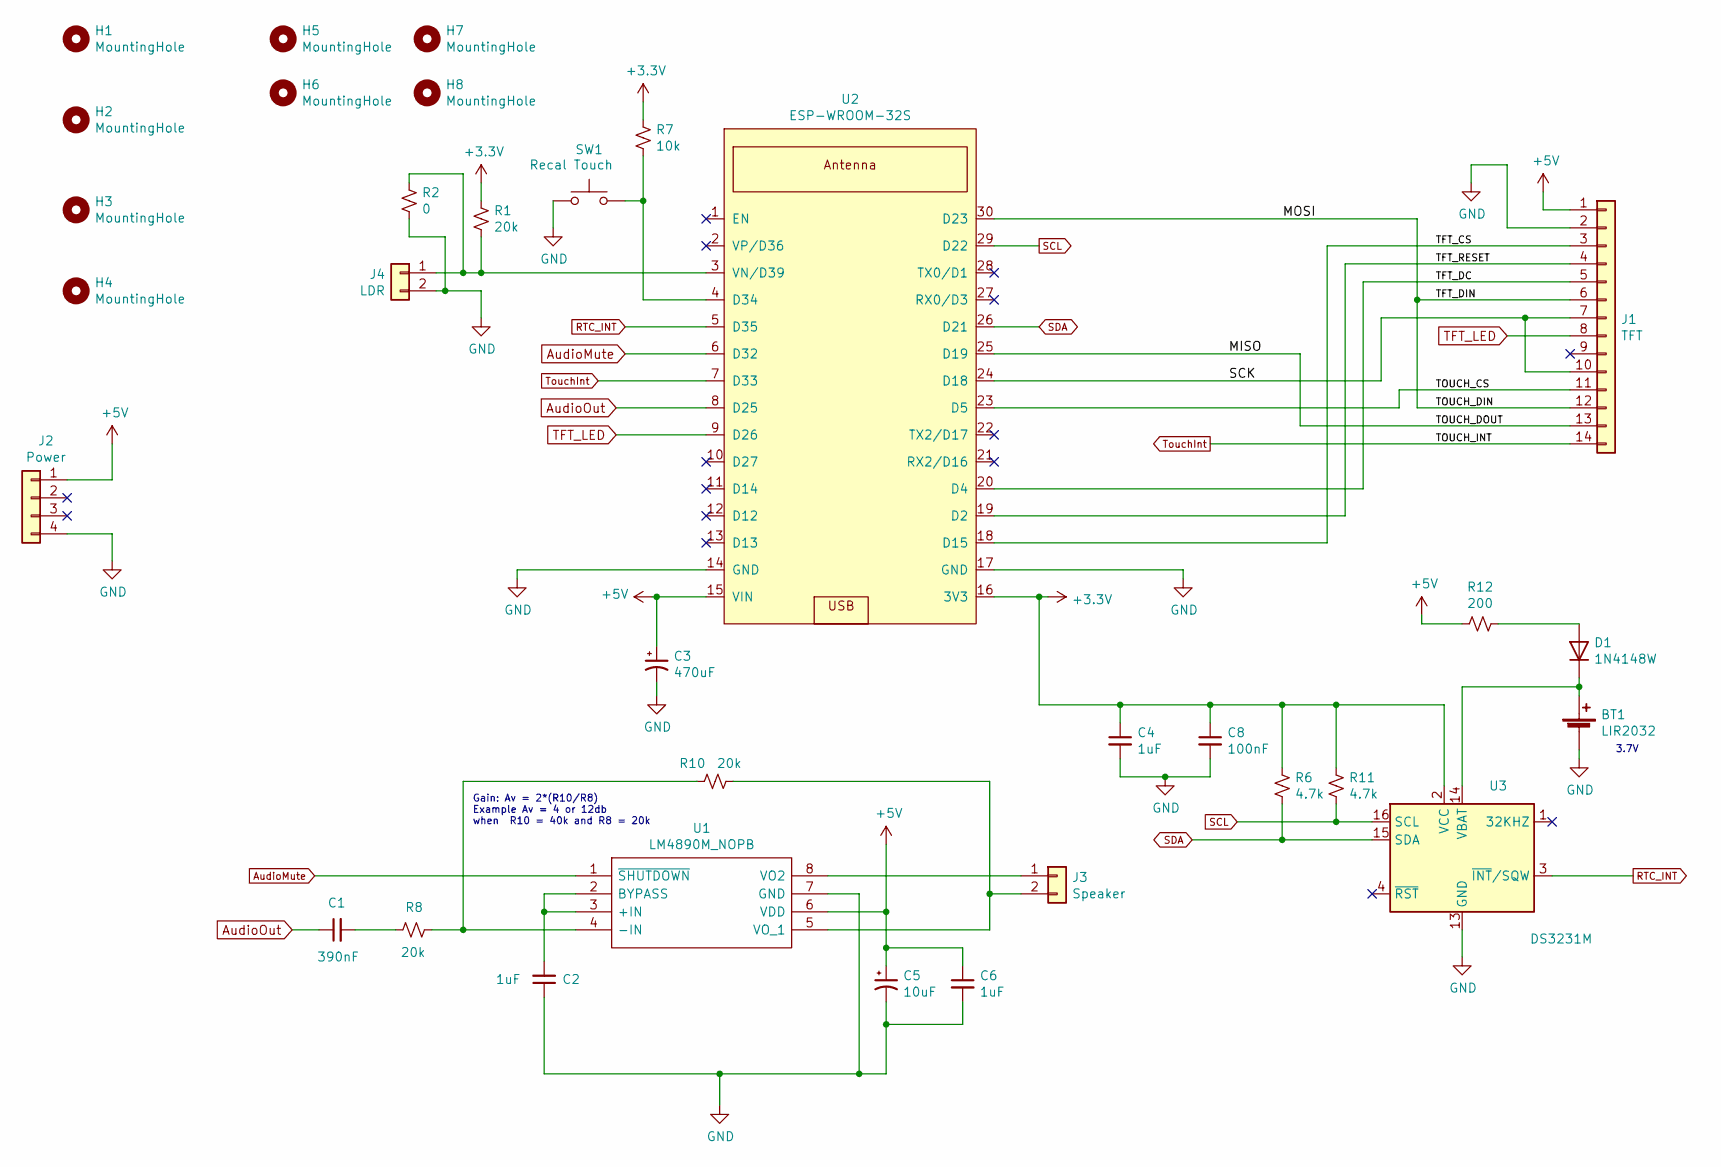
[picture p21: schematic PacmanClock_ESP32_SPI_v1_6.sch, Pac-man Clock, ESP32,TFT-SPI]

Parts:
BT1: LIR2032; 2032BatteryHolderHoriz
C1: 390nF; C_0805_2012Metric_Pad1.18x1.45mm_HandSolder
C2, C4: 1uF; C_1206_3216Metric_Pad1.33x1.80mm_HandSolder
C3: 470uF; CP_Radial_D8.0mm_P3.50mm
C5: 10uF; CP_Radial_D4.0mm_P1.50mm
C6: 1uF; C_0805_2012Metric_Pad1.18x1.45mm_HandSolder
C8: 100nF; C_0805_2012Metric_Pad1.18x1.45mm_HandSolder
D1: 1N4148W; D_SOD-123
H1, H2, H3, H4, H5, H6, H7, H8: MountingHole; MountingHole_2.7mm_M2.5_DIN965
J1: TFT; PinSocket_1x14_P2.54mm_Vertical
J2: Power; JST_XH_B4B-XH-A_1x04_P2.50mm_Vertical
J3: Speaker; JST_XH_B2B-XH-A_1x02_P2.50mm_Vertical
J4: LDR; JST_XH_B2B-XH-A_1x02_P2.50mm_Vertical
R1, R8, R10: 20k; R_0805_2012Metric_Pad1.20x1.40mm_HandSolder
R2: 0; R_0805_2012Metric_Pad1.20x1.40mm_HandSolder
R6, R11: 4.7k; R_0805_2012Metric_Pad1.20x1.40mm_HandSolder
R7: 10k; R_0805_2012Metric_Pad1.20x1.40mm_HandSolder
R12: 200; R_0805_2012Metric_Pad1.20x1.40mm_HandSolder
SW1: Recal Touch; FSM2JRT_gm
U1: LM4890M_NOPB; SOIC-8_3.9x4.9mm_P1.27mm; Manufacturer_Part_Number LM4890M/NOPB; Mouser Part Number 926-LM4890M/NOPB
U2: ESP-WROOM-32S
U3: DS3231M; SOIC-16W_7.5x10.3mm_P1.27mm

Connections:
+3V3: C4.1, C8.1, R1.1, R6.1, R7.1, R11.1, U2.16 (3V3), U3.2 (VCC)
+5V: C3.1, C5.1, C6.1, J1.1, J2.1, R12.2, U1.6 (VDD), U2.15 (VIN)
/MISO: J1.13, U2.25 (D19)
/MOSI: J1.6, J1.12, U2.30 (D23)
/SCK: J1.7, J1.10, U2.24 (D18)
/TFT_CS: J1.3, U2.18 (D15)
/TFT_DC: J1.5, U2.20 (D4)
/TFT_RESET: J1.4, U2.19 (D2)
/TOUCH_CS: J1.11, U2.23 (D5)
AudioMute: U1.1 (~SHUTDOWN), U2.6 (D32)
AudioOut: C1.1, U2.8 (D25)
GND: BT1.2 (-), C2.1, C3.2, C4.2, C5.2, C6.2, C8.2, J1.2, J2.4, J4.2, R2.2, SW1.1, U1.7 (GND), U2.14 (GND), U2.17 (GND), U3.5 (GND), U3.6 (GND), U3.7 (GND), U3.8 (GND), U3.9 (GND), U3.10 (GND), U3.11 (GND), U3.12 (GND), U3.13 (GND)
unnamed: BT1.1 (+), D1.1 (K), U3.14 (VBAT)
unnamed: C1.2, R8.2
unnamed: C2.2, U1.2 (BYPASS), U1.3 (+IN)
unnamed: D1.2 (A), R12.1
unnamed: J3.1, U1.8 (VO2)
unnamed: J3.2, R10.2, U1.5 (VO_1)
unnamed: J4.1, R1.2, R2.1, U2.3 (VN/D39)
unnamed: R7.2, SW1.2, U2.4 (D34)
unnamed: R8.1, R10.1, U1.4 (-IN)
RTC_INT: U2.5 (D35), U3.3 (~INT~/SQW)
SCL: R11.2, U2.29 (D22), U3.16 (SCL)
SDA: R6.2, U2.26 (D21), U3.15 (SDA)
TFT_LED: J1.8, U2.9 (D26)
TouchInt: J1.14, U2.7 (D33)

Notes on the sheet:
3.7V
Gain: Av = 2*(R10/R8) Example Av = 4 or 12db when R10 = 40k and R8 = 20k

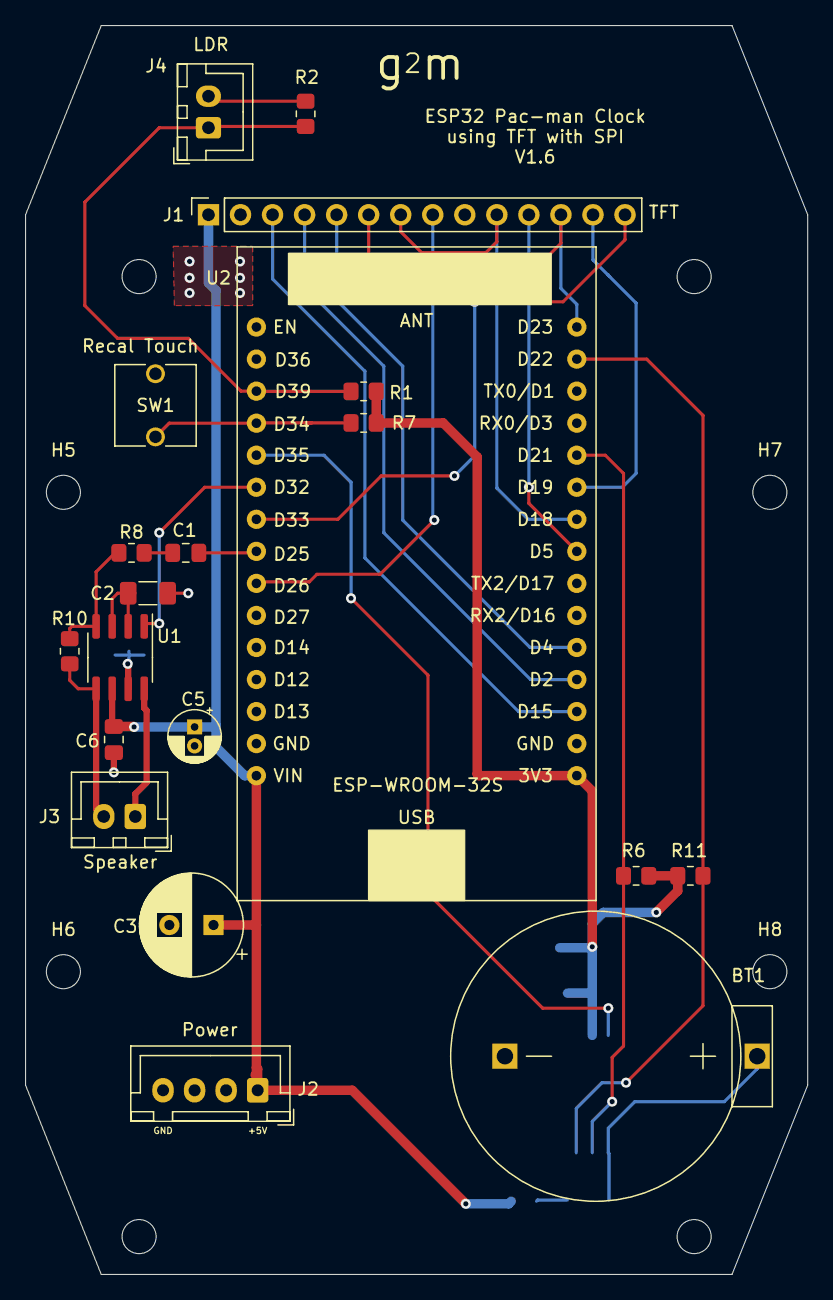
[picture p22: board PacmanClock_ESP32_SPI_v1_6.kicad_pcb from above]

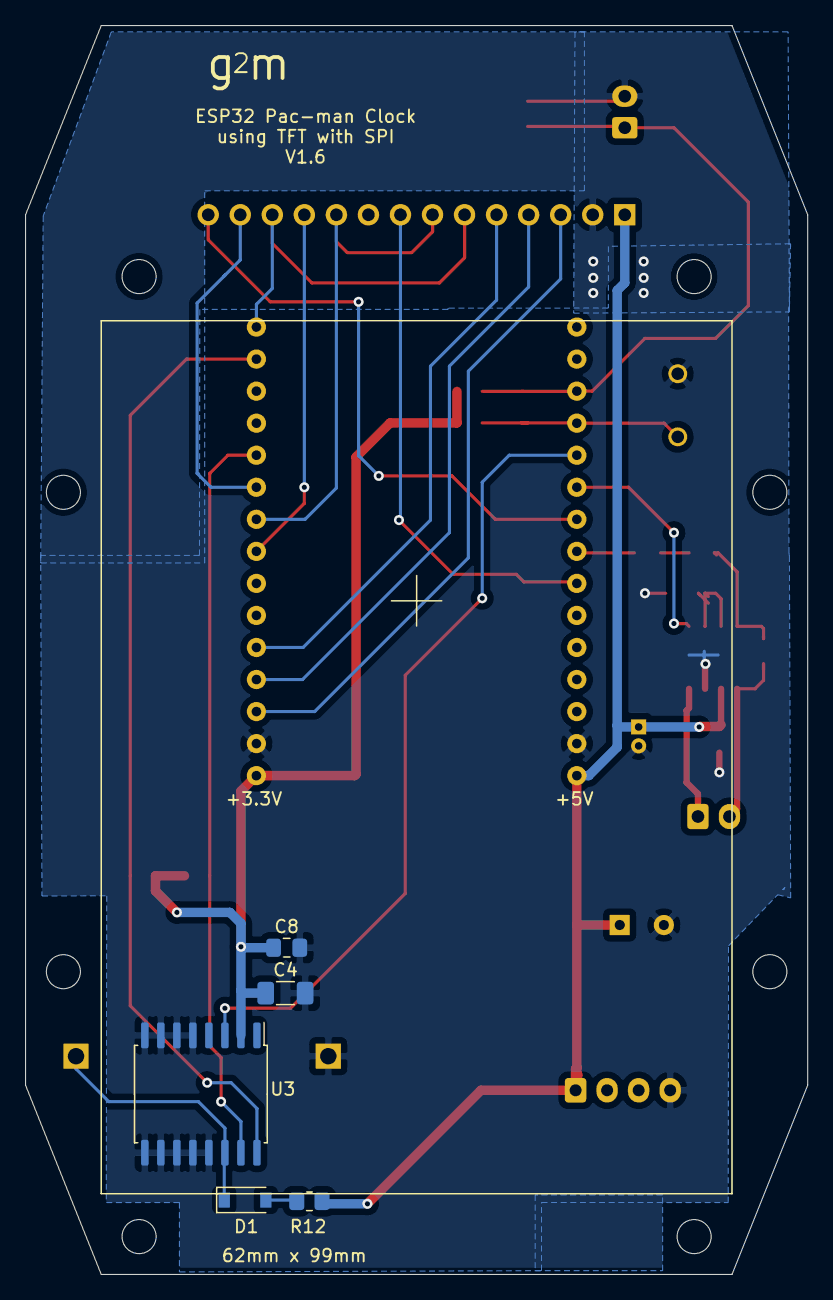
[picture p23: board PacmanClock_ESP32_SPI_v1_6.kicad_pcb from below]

Board: 2 copper layers, 62.0 x 99.0 mm, 33 parts (5 on the bottom side), 26 nets.

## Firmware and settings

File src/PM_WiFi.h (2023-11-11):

//#include <WiFi.h>

//#define DEBUG_WIFI
#ifdef DEBUG_WIFI
#define WIFI_PRINT(x) Serial.print(x)
#define WIFI_PRINTLN(x) Serial.println(x)
#define WIFI_PRINTF(x,y) Serial.printf(x,y)
#else
#define WIFI_PRINT(x)
#define WIFI_PRINTLN(x)
#define WIFI_PRINTF(x,y)
#endif


#define DEFAULT_SSID "ssid"
#define DEFAULT_PASSWORD "password"

const char* hostName = "Pac-manClock";

//GMT Time Zone with sign
//#define GMT_TIME_ZONE -8

struct WIFI_CONFIG_STRUCT {
  char ssID[32];
  char passWord[32];
} WiFiConfig;


#define MAX_NETWORK_CNT 8

struct WIFI_INFO_STRUCT {
  char  localIP[20];
  char  subnetMask[20];
  char  gatewayIP[20];
  char  macAddress[20];
} WiFiInfo;

struct SSID_Struct {
  char ssid[64];
  int rssi;
  int encryptType;
};
struct NETWORK_Struct {
  int count;
  SSID_Struct Tbl[MAX_NETWORK_CNT+2];
} WifiNetworks;



void init_WiFi(void);
void connectWiFi(void);
void disconnectWiFi(void);
String  statusWiFi(void);
int getWiFiQuality(void);

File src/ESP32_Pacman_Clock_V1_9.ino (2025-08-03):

/*  Retro Pac-Man Clock
  Author: @TechKiwiGadgets Date 08/04/2017

  Licensed as Attribution-NonCommercial-ShareAlike 4.0 International (CC BY-NC-SA 4.0)
  You are free to:
  Share — copy and redistribute the material in any medium or format
  Adapt — remix, transform, and build upon the material
  Under the following terms:
  Attribution — You must give appropriate credit, provide a link to the license, and indicate if changes were made. You may do so in any reasonable manner, but not in any way that suggests the licensor endorses you or your use.
  NonCommercial — You may not use the material for commercial purposes.
  ShareAlike — If you remix, transform, or build upon the material, you must distribute your contributions under the same license as the original

  V67 First Instructables release
*/
/*  Extensively modified by Gerald Maurer 2022  --  Version 1.7
      This modified code:
        1. ONLY supports TFT display with SPI interface !!!!!!!!!!
        2. Uses SPIFFS (files) to store configuration parameters, ICONs and WAV files.
        3. Built using "Board: ESP32 Dev Module"
              "Partition Scheme: Minimal SPIFFS (1.9MB APP with OTA/190KB SPIFFS"
        4. Use Arduino IDE tool "ESP32 Sketch Data Upload" to initialize SPIFFS.
        5. Reads WAV files from SPIFFS for sounds (saves about 15000 bytes of memory).
        6. Supports LDR (light dependent resistor) for dimming display when low ambient light (dark room).
        7. Supports volume control in software (via touch screen).
        8. Support for both Pacman and Ms. Pacman (via touch screen).
        9. Uses RTC IC (DS3231) for accurate time keeping.
        10. Uses NTP to set GMT in RTC IC.
        11. Supports many time zones, configured vis touch screen.
        12. Supported time zones tables stored in files (SPIFFS).
*/

/*

  Modifications by Harrie Bosgraaf, August 3, 2025

  I have made some changes to this already highly modified clock:

  1. The two dots between hours and minutes now blink every second.
  2. Added a rectangle around the time display.
  3. Day and date are now shown on screen.
  4. Added the text "ESP32 Pacman Clock" below the time.
  5. Placed a Pacman icon and a ghost icon on the display.
*/

#define FILE_NAME "ESP32_Pacman_Clock_V1_9.ino"

int lastSecond = -1;  // Houdt bij welke seconde we als laatste hebben gecheckt

#define BUFFERED_WAV
#define NTP_ENABLED
//////////////////////////////////////////////////////////////
//  SPKR_MUTE 
//          if defined:  Speaker will be muted when ESP pin D32 is LOW.
//                          Board version V1.4, V1.5, V1.6.
//
//          if undefined:  Speaker will be muted when ESP pin D32 is HIGH.
//                          Board version V1.0 through V1.3.
//
#define SPKR_MUTE

//
//  If Sprite library worked correctly and we used sprites for the Ghost and Pacman
//  we wouldn't have to redraw the dots after the Ghost passed over them.
//
//#define SPRITE        // Sprite library doesn't seem to work correctly.

//
//  The following are for debugging
//    uncomment the '#define' to get debug prints.
//

//#define DEBUG_PACMAN
#ifdef DEBUG_PACMAN
#define PACMAN_PRINT(x) Serial.print(x)
#define PACMAN_PRINTLN(x) Serial.println(x)
#define PACMAN_PRINTF(x,y) Serial.printf(x,y)
#else
#define PACMAN_PRINT(x)
#define PACMAN_PRINTLN(x)
#define PACMAN_PRINTF(x,y)
#endif

//#define DEBUG_CONFIG
#ifdef DEBUG_CONFIG
#define CONFIG_PRINT(x) Serial.print(x)
#define CONFIG_PRINTLN(x) Serial.println(x)
#define CONFIG_PRINTF(x,y) Serial.printf(x,y)
#else
#define CONFIG_PRINT(x)
#define CONFIG_PRINTLN(x)
#define CONFIG_PRINTF(x,y)
#endif

#include "PM_SPIFFS.h"
#include "PM_WiFi.h"
#include "PM_TFT.h"


#include <Arduino.h>
#include "soc/soc.h"           // Disable brownout problems
#include "soc/rtc_cntl_reg.h"  // Disable brownout problems

#include "WiFi.h"
#if defined(NTP_ENABLED)
#include <WiFiUdp.h>
#include <NTPClient.h>
#endif


#include "XT_DAC_Audio.h"
#include "TFT_eSPI.h"
#include <TimeLib.h>
#include <pgmspace.h>

#include "PM_RTC_NTP.h"

#include "Free_Fonts.h"
#include "SoundData.h"

IPAddress localIP;

#define SCREENWIDTH 320
#define SCREENHEIGHT 240

//
//  ESP32 pin definitions
//

//
//  AUDIO pins
//
#define MUTE_PIN  32
// using LM386 audio amplifier
#ifdef SPKR_MUTE                  // muting done at speaker
#define MUTE  LOW
#define UNMUTE  HIGH
#else                             // muting done at LM386
#define MUTE  HIGH
#define UNMUTE  LOW
#endif
#define AUDIO_OUT_PIN 25


unsigned long mlStart = 0;
unsigned long mlEnd = 0;


//
//  TFT Brightness Control definitions
//
// SPI TFT ONLY !!!
#define LED_PWM_CHANNEL    0
#define LED_PWM_FREQ       5000      // 5000Hz
#define LED_PWM_RESOLUTION 8         // 8 bits

#define TFT_LED 26      // TFT LED control pin
#define LDR_PIN 39      // Light dependent resistor

int dutyCycle = 255;    // TFT LED dutycycle  (255 = FULL ON, 0 = OFF)

#define LDR_CHECK_TIME_PERIOD 3000    // three seconds
unsigned long timePeriodStart = 0;

boolean ldrCalibrationFlag = false;
int ldrCalState = 0;

struct LDR_CONFIG_STRUCT {
  boolean cal;
  int daylight;
  int night;
  int step;
  int pad1;
  int pad2;
} LdrConfig;

//
//  SPIFFS files
//   File names (fn.....)
//
const char* fnTftCal = "/tftcal.bin";
const char* fnLdrConfig = "/ldr.bin";
const char* fnWifiConfig = "/wifi.bin";
const char* fnClockConfig = "/config.bin";
const char* fnTimeZoneConfig = "/timezone.bin";
const char* fnBlueGhost = "/blueGhost.bin";
const char* fnRedGhostLeft = "/redGhostL.bin";
const char* fnRedGhostRight = "/redGhostR.bin";
const char* fnRedGhostUp = "/redGhostU.bin";
const char* fnRedGhostDown = "/redGhostD.bin";
const char* fnFruit = "/fruit.bin";
const char* fnPacClosed = "/pacClosed.bin";
const char* fnPacHalf = "/pacHalf.bin";
const char* fnPacOpen = "/pacOpen.bin";
const char* fnMsPacClosed = "/mPacClosed.bin";
const char* fnMsPacHalf = "/mPacHalf.bin";
const char* fnMsPacOpen = "/mPacOpen.bin";
const char* fnWavPM = "/pacman.wav";
const char* fnWavGobble = "/gobble.wav";

char ideVer[32];
String ipAddr;
String macAddr;


#ifdef NTP_ENABLED
//
//  NTP - Network Time Protocol
//
//const char* TZ_INFO = "NZST-12NZDT-13,M9.4.0/02:00:00,M4.1.0/03:00:00";
//const char* TZ_INFO = "PST8PDT,M3.2.0,M11.1.0";   //"PST8PDT";
//const char* ntpServer1 = "uk.pool.ntp.org";

#define GMT_TIME_ZONE 0
#define NTP_SERVER "0.us.pool.ntp.org"

const char* ntpServer1 = "time.nist.gov";
const char* ntpServer2 = "ptbtime1.ptb.de";
const char* ntpServer3 = "pool.ntp.org";

WiFiUDP ntpUDP;

NTPClient timeClient(ntpUDP, NTP_SERVER, GMT_TIME_ZONE);
#endif

//
//  Clock Variables
//
byte clockhour; // Holds current hour value
byte clockminute; // Holds current minute value
byte clocksecond;
struct tm *timeinfo;

unsigned long epochTime = 0;
bool epochTimeValid = false;
      
//
// Alarm Variables
//
//  alarmStatus definitions
#define ALARM_ENABLED true
#define ALARM_DISABLED false
//
//  alarmState definitions
#define ALARM_IDLE 0
#define ALARM_START_SOUND 1
#define ALARM_SOUNDING 2
#define ALARM_QUIET    3
int alarmState = ALARM_IDLE;
int alarmRepeatCount = 0;
int alarmQuietCount = 0;

boolean soundAlarm = false; // Flag to indicate the alarm needs to be initiated
//int actr = 3000; // When alarm sounds this is a counter used to reset sound card until screen touched
//int act = 0;

//
//  Pac-man Clock Configuration data, saved in SPIFFS, restored on boot/reboot
//
struct CLOCK_CONFIG_STRUCT {
  int pad1;
  boolean alarmStatus;
  int alarmHour;  // hour of alarm setting
  int alarmMinute; // Minute of alarm setting
  int speedSetting;
  int alarmVolume;
  boolean mspacman;
  boolean clock24;
  boolean celsiusFlag;
  boolean wifiEnabled;
  int pad3;
} clockConfig;

//
//Dot Array - There are 72 Dots with 4 of them that will turn Ghost Blue!
//
typedef struct DOT_STRUCT {
  bool state;    // true or false, if false it has been gobbled by Pac-Man
  short xPos;
  short yPos;
  byte dotSize;     // small = 2, large = 7
} DOT;


//
//    Dot location Array
//        [state, x, y, size]
//
DOT dots[73] = {
  {0, 0, 0, 0},       // NOT USED
  {true, 19, 19, 2},  // dot 1, Row 1
  {true, 42, 19, 2},
  {true, 65, 19, 2},
  {true, 88, 19, 2},
  {true, 112, 19, 2},
  {true, 136, 19, 2},
  {true, 183, 19, 2},
  {true, 206, 19, 2},
  {true, 229, 19, 2},
  {true, 252, 19, 2}, // dot 10
  {true, 275, 19, 2},
  {true, 298, 19, 2},
  {true, 19, 40, 7},  // dot 13, Row 2  BIG DOT
  {true, 77, 40, 2},
  {true, 136, 40, 2},
  {true, 183, 40, 2},
  {true, 241, 40, 2},
  {true, 298, 40, 7}, // BIG DOT
  {true, 19, 60, 2},  // dot 19, Row 3
  {true, 42, 60, 2},  // dot 20
  {true, 65, 60, 2},
  {true, 88, 60, 2},
  {true, 112, 60, 2},
  {true, 136, 60, 2},
  {true, 160, 60, 2},
  {true, 183, 60, 2},
  {true, 206, 60, 2},
  {true, 229, 60, 2},
  {true, 252, 60, 2},
  {true, 275, 60, 2}, // dot 30
  {true, 298, 60, 2},
  {true, 42, 80, 2},  // dot 32, Row 4
  {true, 275, 80, 2},
  {true, 42, 100, 2}, // dot 34, Row 5
  {true, 275, 100, 2},
  {true, 42, 120, 2}, // dot 36, Row 6
  {true, 275, 120, 2},
  {true, 42, 140, 2}, // dot 38, Row 7
  {true, 275, 140, 2},
  {true, 42, 160, 2}, // dot 40, Row 8
  {true, 275, 160, 2},
  {true, 19, 181, 2}, // dot 42, Row 9
  {true, 42, 181, 2},
  {true, 65, 181, 2},
  {true, 88, 181, 2},
  {true, 112, 181, 2},
  {true, 136, 181, 2},
  {true, 160, 181, 2},
  {true, 183, 181, 2},
  {true, 206, 181, 2},  // dot 50
  {true, 229, 181, 2},
  {true, 252, 181, 2},
  {true, 275, 181, 2},
  {true, 298, 181, 2},
  {true, 19, 201, 7}, // dot 55, Row 10  BIG DOT
  {true, 77, 201, 2},
  {true, 136, 201, 2},
  {true, 183, 201, 2},
  {true, 241, 201, 2},
  {true, 298, 201, 7},  // dot 60  BIG DOT
  {true, 19, 221, 2}, // dot 61, Row 11
  {true, 42, 221, 2},
  {true, 65, 221, 2},
  {true, 88, 221, 2},
  {true, 112, 221, 2},
  {true, 136, 221, 2},
  {true, 183, 221, 2},
  {true, 206, 221, 2},
  {true, 229, 221, 2},
  {true, 252, 221, 2},  // dot 70
  {true, 275, 221, 2},
  {true, 298, 221, 2}
};

//
//  Define the number of Dots in each Row
//
#define DOTS_IN_ROW_1   12
#define DOTS_IN_ROW_2   6
#define DOTS_IN_ROW_3   13
#define DOTS_IN_ROW_4   13
#define DOTS_IN_ROW_5   6
#define DOTS_IN_ROW_6   12

//
//  x axis position for Dots (by Row)
//
short row1n6dots[DOTS_IN_ROW_1] = {4, 28, 52, 74, 98, 120, 168, 192, 216, 238, 262, 284};       // rows 1 & 6
short row2n5dots[DOTS_IN_ROW_2] = {4, 62, 120, 168, 228, 284};                                  // rows 2 & 5
short row3n4dots[DOTS_IN_ROW_3] = {4, 28, 52, 74, 98, 120, 146, 168, 192, 216, 238, 262, 284};  // rows 3 & 4

//
//  Adjacent Dot Lookup Table
//
byte adjacentDots[73][4] = {
  {0, 0, 0, 0},
  {2, 13, 0, 0},    //dot 1, Row 1
  {1, 3, 0, 0},   //dot 2
  {2, 4, 14, 0},    //dot 3
  {3, 5, 14, 0},    //dot 4
  {4, 6, 0, 0},   //dot 5
  {5, 15, 0, 0},    //dot 6
  {8, 16, 0, 0},    //dot 7
  {7, 9, 0, 0},   //dot 8
  {8, 10, 17, 0},   //dot 9
  {9, 11, 17, 0},   //dot 10
  {10, 12, 18, 0},  //dot 11
  {11, 18, 0, 0},   //dot 12
  {1, 19, 0, 0},    //dot 13, Row 2  BIG DOT
  {3, 4, 21, 22},   //dot 14
  {6, 24, 0, 0},    //dot 15
  {7, 26, 0, 0},    //dot 16
  {9, 10, 28, 29},   //dot 17
  {12, 31, 0, 0},   //dot 18  BIG DOT
  {13, 20, 0, 0},   //dot 19, Row 3
  {13, 19, 21, 32}, //dot 20
  {14, 20, 22, 0},  //dot 21
  {14, 21, 23, 0},  //dot 22
  {22, 24, 0, 0},   //dot 23
  {15, 23, 25, 0},  //dot 24
  {24, 26, 0, 0},   //dot 25
  {16, 25, 27, 0},  //dot 26
  {28, 26, 0, 0},   //dot 27
  {17, 27, 29, 0},  //dot 28
  {17, 28, 30, 0},  //dot 29
  {18, 29, 31, 33}, //dot 30
  {18, 30, 0, 0},   //dot 31, end of Row 3
  {20, 34, 0, 0},   //dot 32, column 2
  {30, 35, 0, 0},   //dot 33, column 7
  {32, 36, 0, 0},   //dot 34
  {33, 37, 0, 0},   //dot 35
  {34, 38, 0, 0},   //dot 36
  {35, 39, 0, 0},   //dot 37
  {36, 40, 0, 0},   //dot 38
  {37, 41, 0, 0},   //dot 39
  {38, 43, 0, 0},   //dot 40
  {39, 53, 0, 0},   //dot 41
  {43, 55, 0, 0},   //dot 42, Row 4
  {40, 42, 44, 0},  //dot 43
  {43, 45, 56, 0},  //dot 44
  {44, 46, 56, 0},  //dot 45
  {45, 47, 0, 0},   //dot 46
  {46, 48, 57, 0},  //dot 47
  {47, 49, 0, 0},   //dot 48
  {48, 50, 58, 0},  //dot 49
  {49, 51, 0, 0},   //dot 50
  {50, 52, 59, 0},  //dot 51
  {51, 53, 59, 0},  //dot 52
  {41, 52, 54, 60}, //dot 53
  {53, 60, 0, 0},   //dot 54
  {42, 61, 0, 0},   //dot 55, Row 5  BIG DOT
  {44, 45, 63, 63}, //dot 56
  {47, 66, 0, 0},   //dot 57
  {49, 67, 0, 0},   //dot 58
  {51, 52, 69, 70}, //dot 59
  {54, 72, 0, 0},   //dot 60  BIG DOT
  {55, 62, 0, 0},   //dot 61, Row 6
  {61, 63, 0, 0},   //dot 62
  {56, 62, 64, 0},  //dot 63
  {56, 63, 65, 0},  //dot 64
  {64, 66, 0, 0},   //dot 65
  {57, 65, 0, 0},   //dot 66
  {58, 68, 0, 0},   //dot 67
  {67, 69, 0, 0},   //dot 68
  {59, 68, 70, 0},  //dot 69
  {59, 69, 71, 0},  //dot 70
  {60, 70, 72, 0},  //dot 71
  {60, 71, 0, 0}    //dot 72
};

//
//  ICON definitions
//
#define ICON_SIZE 1568
#define DIR_RIGHT 0
#define DIR_DOWN 1
#define DIR_LEFT 2
#define DIR_UP 3
#define CLOSED_MOUTH 0
#define HALF_OPEN_MOUTH 1
#define OPEN_MOUTH 2

//
//  array of pointers to Pac-man / Ms Pac-man ICONs
//
unsigned short *ptrPacman[3][4];
//
//  array of pointers to Red Ghost ICONs
//
unsigned short *ptrGhost[4];
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
void loop()
{

  drawColonBlinking();

  audioPlayer();  // check to see if anything is playing
  
  setGameSpeed(); // Set game animation speed
  
  printScoreBoard(); //Print scoreboard
  
  drawFruit();  // Draw fruit and allocate points
  
  refreshGame(); // Read the current date and time from the RTC and reset board
 
  mainUserInput(); // Check if user input to touch screen
  
  displayPacman(); // Draw Pacman in position on screen
  
  displayGhost(); // Draw Ghost in position on screen

  delay(dly);

  //
  //  Check LDR every "LDR_CHECK_TIME_PERIOD" for change in light
  //
  if (millis() - timePeriodStart > LDR_CHECK_TIME_PERIOD)
  {
    if(ldrCalibrationFlag)
    {
      ldrCalibration();
    }
    else
    {
      if (digitalRead(REPEAT_CAL_PIN) == 0)
      {
        ldrCalibrationFlag = true;
        ldrCalState = 0;
      }
      setLEDdutyCycle();
    }
    timePeriodStart = millis();
  }
}

//////////////////////////////////////////////////////////
//
//  Set TFT backlight LED duty cycle (brightness)
//
//
//  Sets the TFT backlight LED duty cycle
//    dims LED when room is dark.
//
//
//
//
void setLEDdutyCycle(void)
{
  // read LDR ADC value   // dark ~ 4095,  light ~ 1400
  int light = analogRead(LDR_PIN);
  //Serial.printf("LDR_PIN = %d\n\r", light);
#if 0
  float VR1 = ((4096.0 - (float)light) / 4096.0) * 3.30;
  Serial.printf("R1: V = %f    ", VR1);
  float IR1 = VR1 / 20000.0;
  Serial.printf("I = %f\n\r", IR1);
  float Vldr = 3.3 - VR1;
  Serial.printf("LDR: V = %f    ", Vldr);
  float Rldr = Vldr / IR1;
  Serial.printf("R = %f\n\r", Rldr);
#endif
#if 1
  if( light < (LdrConfig.daylight + LdrConfig.step)) dutyCycle = 255;
  else if( light < (LdrConfig.daylight + (LdrConfig.step * 2))) dutyCycle = 200;
  else if( light < (LdrConfig.daylight + (LdrConfig.step * 3))) dutyCycle = 150;
  else if( light < (LdrConfig.daylight + (LdrConfig.step * 4))) dutyCycle = 100;
  else dutyCycle = 50;
#else
  dutyCycle = (4095 - light) / 10;
  if (dutyCycle > 240) dutyCycle = 255;
  if (dutyCycle < 20) dutyCycle = 20;
#endif
  //Serial.printf("Backlight LED dutycycle = %d\n\r", dutyCycle);
  ledcWrite(LED_PWM_CHANNEL, dutyCycle);
}

///////////////////////////////////////////////////////////
//
//
//
void setGameSpeed()
{
  if (clockConfig.speedSetting == 1) {
    gamespeed = 18;  //22;
  } else if (clockConfig.speedSetting == 2) {
    gamespeed = 12;  //14;
  } else if (clockConfig.speedSetting == 3) {
    gamespeed = 0;
  }
  dly = gamespeed; // Reset the game speed
}

////////////////////////////////////////////////////////////
//
//
//
void printScoreBoard() { //Print scoreboard

  if ((ghostscore >= 94) || (pacmanscore >= 94)) { // Reset scoreboard if over 94
    ghostscore = 0;
    pacmanscore = 0;
    for (int dotarray = 1; dotarray < 73; dotarray++) {

      dots[dotarray].state = true;
    }

    // Blank the screen across the digits before redrawing them
    //  myGLCD.setColor(0, 0, 0);
    //  myGLCD.setBackColor(0, 0, 0);

    myGLCD.fillRect(299  , 87  , 15  , 10  , TFT_BLACK); // Blankout ghost score
    myGLCD.fillRect(7  , 87  , 15  , 10  , TFT_BLACK);   // Blankout pacman score

    drawscreen(); // Redraw dots
  }

  myGLCD.setTextColor(TFT_RED, TFT_BLACK);
  myGLCD.setTextSize(1);          // Text size multiplier

  // Account for position issue if over or under 10

  if (ghostscore >= 10) {
    //  myGLCD.setColor(237, 28, 36);
    //  myGLCD.setBackColor(0, 0, 0);
    myGLCD.drawNumber(ghostscore, 301, 88);
  } else {
    //  myGLCD.setColor(237, 28, 36);
    //  myGLCD.setBackColor(0, 0, 0);
    myGLCD.drawNumber(ghostscore, 307, 88); // Account for being less than 10
  }

  myGLCD.setTextColor(TFT_YELLOW, TFT_BLACK);   myGLCD.setTextSize(1);    // Text size multiplier

  if (pacmanscore >= 10) {
    //  myGLCD.setColor(248, 236, 1);
    //  myGLCD.setBackColor(0, 0, 0);
    myGLCD.drawNumber(pacmanscore, 9, 88);
  } else {
    //  myGLCD.setColor(248, 236, 1);
    //  myGLCD.setBackColor(0, 0, 0);
    myGLCD.drawNumber(pacmanscore, 15, 88); // Account for being less than 10
  }
}

///////////////////////////////////////////////////////////
//
//
//
void drawFruit() { // Draw fruit and allocate points

  // Draw fruit
  if ((fruitdrawn == false) && (fruitgone == false)) { // draw fruit and set flag that fruit present so its not drawn again
    //drawicon(146, 168, fruit); //   draw fruit
    myGLCD.pushImage(146, 168, 28, 28, fruitIcon);
    fruitdrawn = true;
  }

  // Redraw fruit if Ghost eats fruit only if Ghost passesover 172 or 120 on the row 186
  if ((fruitdrawn == true) && (fruitgone == false) && (xG >= 168) && (xG <= 170) && (yG >= 168) && (yG <= 180)) {
    //drawicon(146, 168, fruit); //   draw fruit
    myGLCD.pushImage(146, 168, 28, 28, fruitIcon);
  }

  if ((fruitdrawn == true) && (fruitgone == false) && (xG == 120) && (yG == 168)) {
    //drawicon(146, 168, fruit); //   draw fruit
    myGLCD.pushImage(146, 168, 28, 28, fruitIcon);
  }

  // Award Points if Pacman eats Big Dots
  if ((fruitdrawn == true) && (fruitgone == false) && (xP == 146) && (yP == 168)) {
    fruitgone = true; // If Pacman eats fruit then fruit disappears
    pacmanscore = pacmanscore + 5; //Increment pacman score
  }
}

///////////////////////////////////////////////////////////
//
//  Read the current date and time from the RTC and
//      reset the game board.
//
void refreshGame(void)
{
  if (!digitalRead(RTC_INT_PIN))   // RTC interrupt
  {
    //
    //  RTC alarm #2 interrupt (occurs every minute)
    //
    if (rtc.alarmFired(ALARM_2))  // clear RTC alarm #2 interrupt (occurs once a minute)
    {
      rtc.clearAlarm(ALARM_2);
      UpdateDisp(); // update value to clock then ...
      fruiteatenpacman =  false; // Turn Ghost red again
      fruitdrawn = false; // If Pacman eats fruit then fruit disappears
      fruitgone = false;
      // Reset every minute both characters
      pacmanlost = false;
      ghostlost = false;
      dly = gamespeed; // reset delay
      rfc = 0;
      //
      //  Now check if Alarm needs to be sounded
      //    (only check when minute changes)
      //
      triggerAlarm();
    }
    //
    //  RTC alarm #1 interrupt (occurs every second)
    //
    if (rtc.alarmFired(ALARM_1))  // clear RTC alarm #1 interrupt (occurs every second)
    {
      rtc.clearAlarm(ALARM_1);
      //if (clockConfig.alarmStatus == ALARM_ENABLED) alarmProcessor();
      if (alarmState != ALARM_IDLE) alarmProcessor();
    }
  }
}

///////////////////////////////////////////////////////////
//
//  Check to determine if the Alarm needs to be sounded
//
void triggerAlarm(void)
{
  if ((clockConfig.alarmStatus == ALARM_ENABLED) && (alarmState == ALARM_IDLE))
  {
    if ((clockConfig.alarmHour == clockhour) && (clockConfig.alarmMinute == clockminute))
    { // Sound the alarm
      soundAlarm = true;
      alarmState = ALARM_START_SOUND;
      alarmRepeatCount = 9 * 15;    // 9 per minute for 15 minutes
    }
  }
}

////////////////////////////////////
//
//  Alarm Processor (called once every second if Alarm is enabled)
//
void alarmProcessor(void)
{
  switch (alarmState)
  {
    case ALARM_IDLE:
    {
      digitalWrite(MUTE_PIN, MUTE);
      break;
    }
    case ALARM_START_SOUND:
    {
      Serial.println("ALARM_START_SOUND");
      playPM = true;
      alarmState = ALARM_SOUNDING;
      break;
    }
    case ALARM_SOUNDING:
    {
      //Serial.println("ALARM_SOUNDING");
      if(playPM == false)   // done playing?
      {
        Serial.println("ALARM_QUIET");
        alarmState = ALARM_QUIET;
        alarmQuietCount = 1;
      }
      break;
    }
    case ALARM_QUIET:     // quiet alarm for 2 seconds
    {
      alarmQuietCount--;
      if (alarmQuietCount == 0)
      {
        alarmRepeatCount--;
        if (alarmRepeatCount == 0)
        {
          alarmState = ALARM_IDLE;
          digitalWrite(MUTE_PIN, MUTE);
          Serial.println("Alarm time expired");
        }
        else
        {
          alarmState = ALARM_START_SOUND;
        }
      }
      break;
    }
    default:
      Serial.println("Unknown alarmState");
      break;
  }
}
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

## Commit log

2023-11-11 Initial Release of Retro Clock 2
    See Readme for details.
    [ClockAssembly.FCStd, NU_BEZEL-Part.stl, NU_BEZEL-PartBody1.stl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]
2023-11-12 Update
    Added Clock Schematic file and updated PCB Schematic file
    [PacmanClock_ESP32_SPI_v1_6.csv, PacmanClock_ESP32_SPI_v1_6.sch]
2023-11-12 Update Cable Schematic.pdf
2023-11-12 Added BOM
    Added BOM to DOC directory
    [RetroClock PCB BOM.xlsx]
2025-08-03 Update ESP32_Pacman_Clock_V1_9.ino
    Add blinking dots, date/time frame, icons, and Pacman text
